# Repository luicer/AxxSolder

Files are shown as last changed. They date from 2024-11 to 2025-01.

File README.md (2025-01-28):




<a href='https://ko-fi.com/axxaxx' target='_blank'>Donate  

Interested in purchasing an AxxSolder 3.1? On [Tindie](https://www.tindie.com/stores/axxaxx/) you can purchase assembled and tested AxxSolder 3.1 boards with connectors and hardware.  


# AxxSolder Overview
AxxSolder is a STM32 based soldering iron controller for JBC C115, C210 and C245 style cartridges.  
Two different versions are designed around the same PCB and software - one soldering station based on the [JBC ADS stand](https://www.jbctools.com/ad-sf-stand-for-t210-t245-handles-product-2018.html) and one portable version. The AxxSodler hardware takes a DC input source of 9-24V OR a USB-C Power Delivery source. The recommended power supply is a Meanwell [LRS-150-24](#recommended-power-supply) which can power all compatible JBC irons at full power. If a 65W, 20V USB-PD supply is used then NT115 and T210 handles can be powered at full power and T245 at limited power. The power limiting is automatic and AxxSolder reads the power capability of the USB-PD source during the negotiating phase and reduces the output power accordingly.  
The software is written for the [STM32G431CBT6](https://www.st.com/en/microcontrollers-microprocessors/stm32g431cb.html) and implements a PID controller for temperature regulation, TFT display driver, sleep functions for when the handle is at rest and various user settings to name a few.  
Enclosures for both station and portable versions are 3D printed and design files are available under [/CAD](https://github.com/AxxAxx/AxxSolder/tree/main/CAD). A video showing the AxxSolder station can be found under [DEMO](#demo). A *bill of materials* (BOM) with individual component prices can be found under [/bom](https://github.com/AxxAxx/AxxSolder/tree/main/AxxSolder_hardware/bom).  
coverphoto

# Questions and support
Please use [Discord](https://discord.gg/AwpHEmsyKj) for build related and general questions.

# Table of Contents
- [AxxSolder Overview](#axxsolder-overview)
- [Questions and support](#questions-and-support)
- [Features](#features)
- [DEMO](#demo)
- [Schematic](#schematic)
- [PCB](#pcb)
- [Software Version History and Hardware Compatibility](#software-version-history-and-hardware-compatibility)
- [AxxSolder Station](#axxsolder-station)
- [AxxSolder Portable](#axxsolder-portable)
- [Recommended power supply for tip grounding](#recommended-power-supply-for-tip-grounding)
- [Handle identification and connections](#handle-identification-and-connections)
- [Firmware update](#firmware-update)
- [First start up after build](#first-start-up-after-build)
- [Settings](#settings)
- [PID control](#pid-control)
- [Cartridge differences](#cartridge-differences)
- [Temperature calibration](#temperature-calibration)
- [Temperature measurement](#temperature-measurement)
- [Current measurement](#current-measurement)
- [Disclaimer](#disclaimer)

# Features
- The tip temperature is set by a rotary encoder. Pressing the encoder puts AxxSolder into Sleep mode and heating is turned off, press again to wake up.  
- AxxSolder is capable of driving C115, C210 and C245 style cartridges from JBC. With two handle sense inputs AxxSolder can determine if the connected handle is either a NT115, T210 or T245 and adjust max output power accordingly. The max output power is software limited to 130 W for T245, 65 W for T210 and 22 W for NT115 handles.
- When the handle is put into the stand (connected to Stand_sense) AxxSolder goes into "Standby mode". On the portable version an aluminium plate is mounted in the case and allows the AxxSolder to go into Standby mode when the cartridge or handle rests against it. After 10 min in Standby mode AxxSolder goes into "Sleep mode" and heating is completely turned off. This is similar to what JBC calls [Sleep and Hibernation](https://www.jbctools.com/intelligent-heat-management.html).  
- If AxxSolder is left in normal running mode for longer than 30 min, the station automatically goes into sleep mode after 30 min as a safety feature.  
- Should the temperature ever go higher than 480 deg C overheating is detected and the station goes into sleep mode in order to protect the tip.
- At start-up any USB-PD source is detected and the highest possible power is negotiated. AxxSolder limits the soldering iron output power to the max output power of the USB-PD source automatically. The maximum power output is displayed at the top of the power bar graph on the display.
- User settings are stored in non-volatile flash and can be configured via a settings menu described in [SETTINGS](#settings).
- The two buttons are used to store temperature presets, e.g. 330 deg C and 430 deg C. Both preset temperatures are configurable in the settings menu.
- There is a 3.3 V logic level output (GPIO4) that can be configured to go high when the iron is in Run mode, controlling e.g. fume extractor via a MosFET or relay.
- The TFT display used in this project is a 2 inch 320x240 Color TFT display [2.0" 320x240 Color IPS TFT Display](https://www.adafruit.com/product/4311) and shows information about:
  - Set temperature
  - Actual temperature
  - Current power as a bar graph
  - In case of sleep mode, the power bar shows "ZzZzZz"
  - In case of Standby mode, the power bar shows "STANDBY"
  - Input voltage
  - MCU temperature
  - Current detected handle type
  - Current max power output
  - Current power source USB-PD / DC

# DEMO
YouTube (https://www.youtube.com/watch?v=I5uLvEM9wpY)
[https://www.youtube.com/watch?v=I5uLvEM9wpY](https://www.youtube.com/watch?v=I5uLvEM9wpY)

# Schematic
The schematic for AxxSolder is shown below. Both station and portable versions use the same PCB and software. The MCU is a [STM32G431CBT6](https://www.st.com/en/microcontrollers-microprocessors/stm32g431cb.html). 
AxxSolder_station

# PCB
The PCBs are designed in KiCad and manufactured by [PCBWay](https://www.pcbway.com/). PCBWay has sponsored this project with PCBs and stencils. The support and quality from PCBWay is great and therefore PCBWay is the recommender PCB supplier for this project. As some components have a rather fine pitch (0,5 mm as of the LQFP-48 package of the STM32) and some packages are "no lead" with a bottom thermal pad e.g. the WSON-8 package of the OPA2387 it is recommended to use a stencil to apply solder paste and then reflow the board using either a reflow oven or hot-plate. The boards on the image below were reflowed on a hot-plate (a homemade AxxPlate). A microscope is also recommended and helpful during assembly.
Printed Circuit Boards with assembled components are shown in the image below.
PCB_image
A 3D view (from and back) of the AxxSolder PCB is generated with KiCad and shown below. 
PCB_3D

# Software Version History and Hardware Compatibility
| Version | Date  | Hardware Compatibility |
|---|---|---|
|[v3.3.1](https://github.com/AxxAxx/AxxSolder/releases/tag/v3.3.1)|Jan 18, 2025|V3.*|
|[v3.3.0](https://github.com/AxxAxx/AxxSolder/releases/tag/v3.3.0)|Jan 04, 2025|V3.*|
|[v3.2.5](https://github.com/AxxAxx/AxxSolder/releases/tag/v3.2.5)|Jan 02, 2025|V3.*|
|[v3.2.4](https://github.com/AxxAxx/AxxSolder/releases/tag/v3.2.4)|Dec 26, 2024|V3.*|
|[v3.2.3](https://github.com/AxxAxx/AxxSolder/releases/tag/v3.2.3)|Dec 05, 2024|V3.*|
|[v3.2.2](https://github.com/AxxAxx/AxxSolder/releases/tag/v3.2.2)|Nov 15, 2024|V3.*|
|[v3.2.1](https://github.com/AxxAxx/AxxSolder/releases/tag/v3.2.1)|Sep 21, 2024|V3.*|
|[v3.2.0](https://github.com/AxxAxx/AxxSolder/releases/tag/v3.2.0)|Aug 13, 2024|V3.*|
|[v3.1.0](https://github.com/AxxAxx/AxxSolder/releases/tag/v3.1.0)|Jun 5, 2024|V3.*|
|[v3.0.2](https://github.com/AxxAxx/AxxSolder/releases/tag/v3.0.1)|Apr 25, 2024|V3.*|
|[v3.0.1](https://github.com/AxxAxx/AxxSolder/releases/tag/v3.0.1)|Mar 26, 2024|V3.*|
|[v3.0.0](https://github.com/AxxAxx/AxxSolder/releases/tag/v3.0.0)|Mar 02, 2024|V3.*|
|[v2.2.4](https://github.com/AxxAxx/AxxSolder/releases/tag/v2.2.2)|Dec 11, 2023|V2.*|
|[v2.2.4](https://github.com/AxxAxx/AxxSolder/releases/tag/v2.2.2)|Nov 28, 2023|V2.*|
|[v2.2.3](https://github.com/AxxAxx/AxxSolder/releases/tag/v2.2.2)|Nov 25, 2023|V2.*|
|[v2.2.2](https://github.com/AxxAxx/AxxSolder/releases/tag/v2.2.2)|Oct 24, 2023|V2.*|
|[v2.2.0](https://github.com/AxxAxx/AxxSolder/releases/tag/v2.2.0)|Oct 20, 2023|V2.*|
|[v2.1.3-revC](https://github.com/AxxAxx/AxxSolder/releases/tag/v2.1.3-revC)|Oct 16, 2023|V2.*|
|[v2.1.1](https://github.com/AxxAxx/AxxSolder/releases/tag/v2.1.1)|Oct 7, 2023|V2.*|
|[v2.1.0](https://github.com/AxxAxx/AxxSolder/releases/tag/v2.1.0)|Oct 7, 2023|V2.*|

# AxxSolder Station
The preferred setup is to pair AxxSolder with the [JBC ADS stand](https://www.jbctools.com/ad-sf-stand-for-t210-t245-handles-product-2018.html). This makes a very nice, compact and powerful soldering station. The JBC ADS stand is paired with a custom 3D printed enclosure for AxxSolder and the PCB is mounted with two mounting brackets. All 3D printed parts are available under [/CAD](https://github.com/AxxAxx/AxxSolder/tree/main/CAD). 
AxxSolder_station  
The JBC ADS stand comes with a silicone cable fitted with two Binder 99-0621-00-07 connectors. In order to use this cable a Binder 99-0624-00-07 is mounted into the AxxSolder enclosure and wired as the image below:  
AxxSolder_station  
By default, the stand separates the two signals coming from the "tool rest position" and the "tip change position" and does NOT have two separate connections for tip sensing 1 and 2 as is needed if NT115, T210 and T245 handles should all be automatically detected. Therefore, a modification is done to the PCB inside the JBC ADS stand in order to combine the "tool rest position" and the "tip change position" sense into one connection and separate the two tip sense connections. This is shown in the image above. The stand is held together with two PH0 screws from the side.  
NOTE: This modification of the stand is NOT necessary if you know that you will not be using NT115 handles and only require automatic detection of T210 and T245 handles.  
The JBC ADS stand is a expensice piece and thankfully there are many alternatives online for the one who wants to save some money. The community on the AxxSolder Discord channel has created many enclosures for alternative stands.

# AxxSolder Portable
It is often nice to have a compact and portable soldering iron controller for when you are away from your comfortable desk. A neat powerful package with the same capabilities as your main soldering station. This is why AxxSolder Portable was designed. The only difference between AxxSolder station and Portable is the enclosure.  
As AxxSolder accepts an input of 9-24 V it is compatible with a range of battery options. The author usually use a battery pack consisting of 12 Samsung INR18650 35E in a 3S4P configuration which works very well.  
The portable version has an aluminium tab on the enclosure connected to the same input on the PCB as the "handle rest" on the station version. This allows the user to rest the iron onto the aluminium tab and automatically enter sleep mode.   
AxxSolder_portable
The connections from the handle to the PCB through the Hirose RPC1-12RB-6P(71) connector is shown below. The Stand_sense in the portable version is connected to the aluminium plate which tells the AxxSolder to go into sleep mode when in contact with the soldering iron.  
AxxSolder_portable

# Recommended power supply for tip grounding
In order to be able to ground the tip of the soldering iron the user MUST use a power supply with a floating output (SELV) and connect protective earth to the ground terminal on AxxSolder. No other devices should share this DC power other than AxxSolder itself. A well-suited power supply with floating output (SELV) is the Meanwell LRS-150-24. It is rated for 156 W at 24 V. By using this kind of power supply, AxxSolder can be connected directly its DC output and to mains earth thus keeping the tip of the soldering iron at earth ground potential. There is a 1A fuse after the earth terminal in paralell with a 1M resistor on the AxxSolder.  
A printable cover protecting the terminals of the for LRS-150-24 can be found under [/CAD](https://github.com/AxxAxx/AxxSolder/tree/main/CAD).  
LRS-150-24
Another suitable power supply is the Meanwell XLG-150-24 which has a slightly different form factor and is fully enclosed.

# Handle identification and connections
In order for AxxSolder to know which type of handle (NT115, T210, T245) is attached specific pins inside the handle connector must be connected (bridged with a jumper wire). By default, the original JBC handle T245 has NO bridged pins while inside the connector of the original JBC T210 the pins 5 and 6 are bridged with a jumper wire. The original NT115 handle from JBC has a different connector and must be modified accordingly. All the necessary connections are shown in the image below.  
When powering on AxxSolder for the first time after doing these connections inside the handle connector it is wise to attach a handle without its cartridge and ensure that AxxSolder detects and shows the correct handle type on the display.  
Failing to detect the handle type may cause permanent damage to the cartridge as the temperature calibration and max allowed power will be wrong.  
❗WARNING❗ It has been discovered that some JBC clones have different pins bridged by the manufacturer. For example: Some AiXun T210 handles have pin 1 and 6 bridged, instead of pin 5 and 6 as AxxSolder requires for T210 handles. It is however easy to open up the connector and do the required pin connection.      
Handle_connections

# Firmware update
Flashing or updating the firmware on the STM32 MCU can be done in two ways, by using a SWD programmer or directly via USB. 
There is a bug in the new ST Programmer software version 2.17 throwing the error: "Error: Database: There's no active configuration for this device.  All the 3 configurations are disabled!" when trying to connect to the MCU.  
Download version 2.15 instead:
STprogrammer_2_15

## SWD programmer
These come in a variety of models and are available from several different places online. In the below example a [STLINK-V3MINIE](https://www.st.com/en/development-tools/stlink-v3minie.html) SWD programmer is used. The MCU is programmed by the following steps:
1. Disconnect any soldering iron handles from AxxSolder during the firmware update process.
2. Download the latest AxxSolder.bin file from [Releases](https://github.com/AxxAxx/AxxSolder/releases)
3. Connect your SWD programmer to the target MCU with GND, 3.3V, (N)RST, SWCLK, SWDIO
4. If your SWD programmer *can not* supply 3.3V it is necessary to power the AxxSolder from an external supply.
5. Start your programming software. [STM32CubeProgrammer](https://www.st.com/en/development-tools/stm32cubeprog.html) is used in this example.
6. Connect to the target by selecting *ST-LINK* and click on *Connect*
7. Load the latest AxxSolder.bin downloaded in *Step 2* by clicking *Open file* and select the downloaded binary file.
8. Write the firmware to the MCU by clicking *Download*.
9. If you get the message *File download complete* everything succeeded and the SWD programmer can be disconnected and AxxSolder power cycled once and AxxSolder should boot.


AxxSolder_SWD_programming
## USB (DFU mode)
1. Disconnect any soldering iron handles from AxxSolder during the firmware update process.
2. Download the latest AxxSolder.bin file from [Releases](https://github.com/AxxAxx/AxxSolder/releases)
3. Connect AxxSolder via USB to a computer that runs [STM32CubeProgrammer](https://www.st.com/en/development-tools/stm32cubeprog.html).
4. Hold down the most right button while powering on AxxSolder to enter DFU mode.
5. Connect to the target by selecting *USB* and click on *Connect*
6. Load the latest AxxSolder.bin downloaded in *Step 2* by clicking *Open file* and select the downloaded binary file.
7. Write the firmware to the MCU by clicking *Download*.
8. If you get the message *File download complete* everything succeeded and the USB cable can be disconnected.
9. Power cycle once and AxxSolder should boot.

# First start up after build
The first start up after you have built your AxxSolder can be intense. Double check all solder connections under a loupe/microscope. Especially the OPA2387, LTC4440 and the STM32G431 are small packages with tight pad spacing and can have solder bridges. Do also double check the connections to the soldering iron/stand which are shown in this document under [AxxSolder Station](#axxsolder-station) and [AxxSolder Portable](#axxsolder-portable).  
The first thing to do after you have double-checked everything is to follow the steps under [Firmware update](#firmware-update). It is wise to do the first programming of AxxSolder without any handle piece and with only 3.3 V, not VDD. After the programming is done you can now power up AxxSolder again via either with 3.3 V, this time you can attach your handle. This allows you to test that your handle type is detected correctly (the detected handle type NT115/T210/T245 is shown in the display). The Standby feature can also be tested by touching the stand (STAND Input).  
If the handle is detected correctly, the Standby function works and the display works you proceed to test the 7.35V DC/DC. This is done by once again disconnect the handle, but this time apply current limited 9-24 V VDD. 100 mA at 24 V is enough to check that the display starts and that you can measure the 3 bus voltages; 3.3V, 7.35V and VDD. If the bus voltages look good and the display shows the main screen you are ready to apply full VDD power and attach the soldering handle.  
If you are not 110% sure about your soldering/connections it is wise to be on the safe side and keep your soldering tip in a water bath in over to prevent it from over-heating in an uncontrolled manner. During the development this method was used and saved a few of those expensive JBC cartridges..

# Settings
To access the user settings the user holds down the encoder button at start-up. A SETTINGS text is then presented and the button can be released. While in the settings there are several parameters available.
| Setting | Description  | Unit | Default |
|---|---|---|---|
|Startup Temp °C|Default temperature selected after boot|deg C|330|
|Temp Offset °C|Temperature offset applied to measured temperature|deg C|0|
|Standby Temp °C|Temperature to go to after handle is set in stand|deg C|150|
|Standby Time [min]|Time for which standby temperature is held before cooling down|minutes|10|
|Sleep Time [min]|Time that the iron can be ON before cooling down (safety feature)|minutes|30|
|Buzzer Enable|Enable or Disable the buzzer|ON/OFF|ON|
|Preset Temp 1 °C|Preset temperature for button 1|deg C|330|
|Preset Temp 2 °C|Preset temperature for button 2|deg C|430|
|GPIO4 ON at run|Enable 3.3V output on GPIO4 when the iron is in run mode|ON/OFF|OFF|
|Screen rotation|Rotate the screen|"0"=-180 deg, "1"=-90 deg, "2"=0 deg, "3"=90 deg|2|
|Limit Power [W]|Limit the output power|"0"=no user limit, "5"=5 W, "10"= 10 W, "15"= 15 W ...|0|
|I measurement|Measure the heater current|ON/OFF|ON
|Startup beep|Beep after startup|ON/OFF|ON
|Temp in celcius|Show temperatures in Celcius and not Fahrenheit|ON/OFF|ON
|Temp cal 100 °C|Actual temperature at 100 °C|deg C|100|
|Temp cal 200 °C|Actual temperature at 200 °C|deg C|200|
|Temp cal 300 °C|Actual temperature at 300 °C|deg C|300|
|Temp cal 350 °C|Actual temperature at 350 °C|deg C|350|
|Temp cal 400 °C|Actual temperature at 400 °C|deg C|400|
|Temp cal 450 °C|Actual temperature at 450 °C|deg C|450|
|Serial DEBUG|Print debug over serial|ON/OFF|OFF|
|Displayed temp filter|Moving average filter length|Lenght|5|
|Startup temp is previous temp|Startup temp is previous used temp|ON/OFF|OFF|
|3-button mode|Use 3-button mode|ON/OFF|OFF|
|-Load Default-|Load default parameters|N/A|N/A|
|-Save and Reboot-|Exit and Save|N/A|N/A|
|-Exit no Save-|Exit without Save|N/A|N/A|

# PID control
The thermal mass and heat convection differs between different tip designs. Therefore the PID parameters should in theory be adjusted to each different cartridge. As a matter of simplification, the PID parameters are only different between the different handle types, NT115, T210 and T245. This gives a good thermal performance in conducted tests.
```c
/* Cartridge type specific PID parameters */
#define KP_NT115        5
#define KI_NT115        2
#define KD_NT115        0.3
#define MAX_I_NT115     300

#define KP_T210         7
#define KI_T210         4
#define KD_T210         0.3
#define MAX_I_T210      300

#define KP_T245         8
#define KI_T245         2
#define KD_T245         0.5
#define MAX_I_T245      300

/* General PID parameters */
#define PID_MAX_OUTPUT          500
#define PID_UPDATE_INTERVAL     25
#define PID_ADD_I_MIN_ERROR     75
double PID_NEG_ERROR_I_MULT =   7;
double PID_NEG_ERROR_I_BIAS =   1;

/* Max allowed power per handle type */
#define NT115_MAX_POWER         22
#define T210_MAX_POWER 	        65
#define T245_MAX_POWER 	        130
```
The PID parameters are adjusted to achieve a fast response with minimum overshoot and oscillation. The below image is showing the set temperature, actual temperature response as well as the P, I and D contributions during a heat-up cycle from 25 deg C to 330 deg C. This heat-up sequence takes ~1.5 seconds for a C210-007 cartridge.  

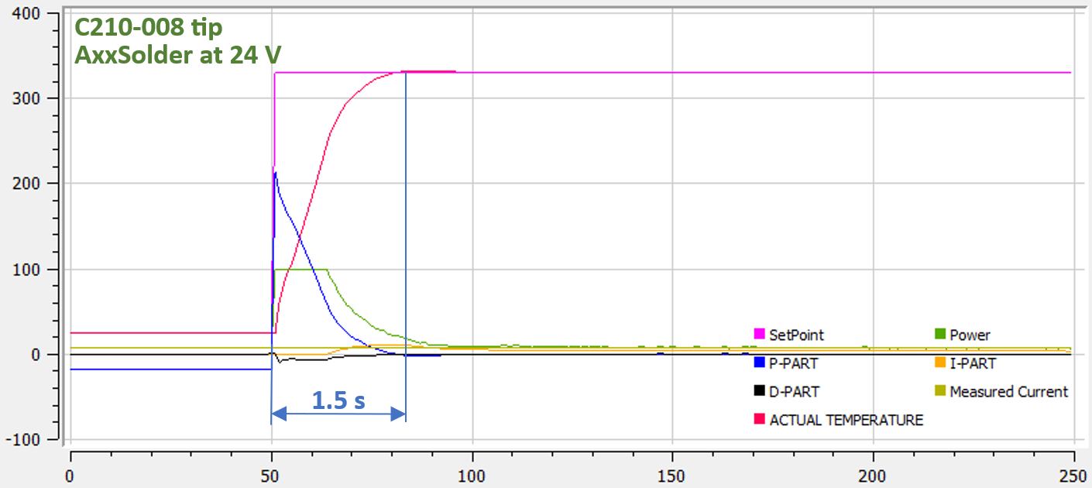
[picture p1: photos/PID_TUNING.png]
AxxSolder_pid
 

# Cartridge differences
Cartridges from JBC do all contain a thermocouple element to read the tip temperature and a resistive heater element. The configuration of thermocouple and heater element differ slightly between cartridge models. In order to determine the internal configuration of the cartridges two cross sections were done. These show clearly how the C210 and C245 cartridges are constructed internally. The images can be seen here: [https://www.eevblog.com/forum/projects/axxsolder-jbc-soldering-controller](https://www.eevblog.com/forum/projects/axxsolder-jbc-soldering-controller/msg5124267/#msg5124267).  
As the thermocouple output also differs (see my measurements [Temperature calibration](#temperature-calibration)) the correct handle/cartridge type has to be set. This is done automatically be the inputs "Handle_sense_1" and "Handle_sense_2" This can be done thanks to the design of the handle connector. For the JCB T210 handle pin 5 and 6 are connected internally in the connector and for NT115 pin 3 and 5 should be connected. This allows AxxSolder to sense which handle is connected and assign correct thermocouple correction, PID parameters and max output power.
 
# Temperature calibration
The voltage from the thermocouple embedded inside the cartridge is amplified by an OPA2387 operational amplifier and then read by the ADC of the MCU. To correlate the measured ADC value to the cartridge temperature experiments were done. A constant power was applied to the heating element of the cartridge and the ADC value was read as well as the actual tip temperature. The tip temperature was measured by a "Soldering Tip Thermocouple" used in e.g. the Hakko FG-100.   
The measured data was recorded and plotted for both the C115, C210 and C245 cartridges. The specific cartridges used were the C115112, C210-007 and C245-945. The measured data were fitted to polynomial equations:  
$Temp_{C115}[deg] =  5.10e^{-5} * ADC^2 + 0.42* ADC + 20.15$  
$Temp_{C210}[deg] =  4.22e^{-6} * ADC^2 + 0.32* ADC + 20.97$  
$Temp_{C245}[deg] = -4.73e^{-7} * ADC^2 + 0.12* ADC + 23.78$  
These are then used in the software to retrieve correct tip temperatures.
Temp_calibration

The user can adjust the temperature calibration at 6 points in order to compensate for variations in the cartridge thermocouple.  
To calibrate temperature(s):
- Make sure that the temperature calibration values are at their default nominal values in the settings.
- Set AxxSolder to the temperature that you want to calibrate. for example 300 deg C.
- When AxxSolder stabilizes around the setpoint, measure the actual tip temperature by using a soldering tip thermocouple, for example the HAKKO FG-100B.
- Input the actual measured temperature, let's say 302 deg C into the 300 deg C calibration setting ("Temp cal 300" = 302).
  
AxxSolder will then use this calibration point and correct the temperature accordingly. It will do so linearly between all calibration points.

# Temperature measurement
As the thermocouple and heater element is connected in series inside the JBC cartridges and the thermocouple voltage measures over the same pins as the heating element we have to be careful when to do the temperature measurement. In order to not disturb the thermocouple measurement with heater element switching, the switching is turned off for 0.5 ms just before the temperature measurement is taken. The 0.5 ms delay ensures that the switching is turned off and the thermocouple signal is stabilized around a stable voltage.  
The measured signal over the thermocouple is clamped to 3.3V with a BAV199 Schottky diode in order to protect the op-amp OPA2387. The voltage measurement is taken by the internal ADC in DMA mode with a circular buffer. The buffer holds several measurements which are averaged and filtered in software.  
The yellow curve in the image below (Channel 1) shows the PWM signal driving the gate of the MOSFET.  
The green curve shows the amplified voltage between GREEN and RED wire in the JBC handle for at 330 degree C and 5% power and the purple 25 degree C and at 80% power (the tip held under water trying to heat up).  
The blue pulse indicates the wait time of 0.5 ms and the purple pulse is where the ADC is sampled.
Oscilloscope_image_PWM
# Current measurement
The current is sampled four times per second by a 30 us current pulse through the heater. This is done both to check if there is a functioning tip in the handle (otherwise the display shows "---" at current temp) and to be able to calculate the power drawn by the heater. By knowing how much the heater draws in ampere the actual power can be calculated by knowing the bus voltage and pulse duty cycle. to measure the current the gate to the MOSFET is turned on, 10 us later the voltage over the current shunt is sampled by the ADC and the result is converted. This is shown the image below.
Oscilloscope_image_PWM
# Disclaimer
AxxSolder is an open source project and has absolutely no warranty, or guarantees on functionality or reliability! The authors of this project accept absolutely no liability for any harm or loss resulting from its use. That said, have fun. :)
## Stargazers over time
Stargazers over time (https://starchart.cc/AxxAxx/AxxSolder)

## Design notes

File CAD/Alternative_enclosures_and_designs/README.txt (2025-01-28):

In this folder you can find alternative CAD models of enclosures that others have designed.

The owner (AxxAxx) of the AxxSolder repo do not take credit nor provide support for these designs. 
But they are probably very nice and of good quality if they have been merged into here! :)

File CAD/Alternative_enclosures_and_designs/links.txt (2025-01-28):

https://www.printables.com/model/894013-mini-iron-man-soldering-station-for-jbc-handpieces
https://www.printables.com/model/875115-25u-19-inch-rack-front-panel-mount-for-axxsolder-3

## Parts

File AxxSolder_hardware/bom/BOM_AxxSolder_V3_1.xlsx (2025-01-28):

AxxSolder V3.1 | Prises as per 2024-02-20 | Parts for AxxSolder Portable
 |  | Parts for AxxSolder Station
References | Value | Footprint | Manufacturer | MPN | Mouser Part Number | Quantity | Price per part | Price total | Price total inc tax
C3, C9, C14, C15, C16, C17, C18, C21, C22, C23, C24, C25, C26, C27, C28, C29, C33 | 100n | C_0603_1608Metric | KEMET | C0603C104J5RACTU | 80-C0603C104J5R | 17 | 0.04 € | 0.73 € | 0.91 €
C1, C2, C5, C7, C8, C10, C11, C12, C13, C19, C20, C30, C31, C32, C34, C35 | 10u | C_0603_1608Metric | Murata Electronics | GRM188R6YA106MA73J | 81-GRM188R6YA106MA3J | 16 | 0.18 € | 2.83 € | 3.54 €
C4, C6 | 1n | C_0603_1608Metric | KEMET | C0603C102K3GAC | 80-C0603C102K3G | 2 | 0.09 € | 0.19 € | 0.23 €
C37 | 220u | CAPAE830X1050N | KEMET | EEV227M035A9MAA | 80-EEV227M035A9MAA | 1 | 0.61 € | 0.61 € | 0.77 €
R4, R6, R18, R19, R20, R22, R23, R25, R26, R27, R28, R29, R30, R31, R32, R33, R35, R36, R37, R38 | 4k7 | R_0603_1608Metric | Panasonic | ERJ-3RBD4701V | 667-ERJ-3RBD4701V | 20 | 0.12 € | 2.50 € | 3.12 €
R11, R12, R15, R21, R24 | 22k | R_0603_1608Metric | Panasonic | ERJ-UP3J223V | 667-ERJ-UP3J223V | 5 | 0.14 € | 0.70 € | 0.88 €
R1, R5, R14, R17 | 1k5 | R_0603_1608Metric | Panasonic | ERJ-H3ED1501V | 667-ERJ-H3ED1501V | 4 | 0.21 € | 0.86 € | 1.07 €
R2, R7, R8, R9 | 360k | R_0603_1608Metric | Panasonic | ERJ-3RED3603V | 667-ERJ-3RED3603V | 4 | 0.12 € | 0.48 € | 0.60 €
R3, R10 | 220k | R_0603_1608Metric | Panasonic | ERJ-3RED2203V | 667-ERJ-3RED2203V | 2 | 0.12 € | 0.24 € | 0.30 €
R13, R16, R34, R43, R46, R47, R48 | 100 | R_0603_1608Metric | Panasonic | ERJ-P03F1000V | 667-ERJ-P03F1000V | 7 | 0.31 € | 2.15 € | 2.69 €
R42 | 5m | RESC6432X89N | Vishay | WSLP25125L000FEA | 71-WSLP25125L000FEA | 1 | 0.75 € | 0.75 € | 0.94 €
R44 | 1M | R_0805_2012Metric | Panasonic | ERJ-6GEYJ105V | 667-ERJ-6GEYJ105V | 1 | 0.09 € | 0.09 € | 0.12 €
R45 | 100m | R_0805_2012Metric | Panasonic | ERJ-6DSFR10V | 667-ERJ-6DSFR10V | 1 | 0.41 € | 0.41 € | 0.51 €
L1 | SRP7028CC-150M | INDPM7366X300N | Bourns | SRP7028CC-150M | 652-SRP7028CC-150M | 1 | 0.75 € | 0.75 € | 0.94 €
D5, D6, D7, D8 | BAT54S | SOT95P230X110-3N | Diotec Semiconductor | BAT54S | 637-BAT54S | 4 | 0.11 € | 0.45 € | 0.56 €
D1, D2 | BAV199WQ-7 | SOT65P210X110-3N | Diodes Incorporated | BAV199WQ-7 | 621-BAV199WQ-7 | 2 | 0.20 € | 0.39 € | 0.49 €
D3, D4 | SMF4L24AT1G | SODFL3619X98N | LITTELFUSE | SMF4L24AT1G | 576-SMF4L24AT1G | 2 | 0.40 € | 0.80 € | 1.00 €
D9, D10 | PMEG6020ER | PMEG6020ER115 | Nexperia | PMEG6020ER,115 | 771-PMEG6020ER-115 | 2 | 0.37 € | 0.74 € | 0.93 €
TFT1 | Adafruit_240x320_TFT | Adafruit_240x320_TFT | Adafruit | 4311 | 485-4311 | 1 | 18.55 € | 18.55 € | 23.19 €
U2 | RIC11-31S15D7-GSMT | RIC11-31S15D7-GSMT | CUI Devices (https://eu.mouser.com/manufacturer/cui-devices/) | RIC11-31S15D7-GSMT | 179-RIC1131S15D7GSMT | 1 | 2.37 € | 2.37 € | 2.96 €
U3 | BSC014N04LS | BSC014N04LS | Infineon Technologies | BSC014N04LSATMA1 | 726-BSC014N04LSATMA1 | 1 | 1.60 € | 1.60 € | 2.00 €
F1 | 0154007.DR | 0154100DR | LITTELFUSE | 0154007.DR | 576-0154007.DR | 1 | 2.55 € | 2.55 € | 3.19 €
F2 | SF-2410FP100W-2 | SF2410FP100W2 | Bourns | SF-2410FP100W-2 | 652-SF-2410FP100W-2 | 1 | 0.72 € | 0.72 € | 0.91 €
S2, S3 | ADTSM644RVTR | ADTSM644RVTR | Apem | ADTSM644RVTR | 642-ADTSM644RVTR | 2 | 0.55 € | 1.10 € | 1.37 €
FB1 | BLM18HE601SN1D | R_0603_1608Metric | Murata Electronics | BLM18HE601SN1D | 81-BLM18HE601SN1D | 1 | 0.18 € | 0.18 € | 0.22 €
IC1 | TLV76733DRVR | SON65P200X200X80-7N | Texas Instruments | TLV76733DRVR | 595-TLV76733DRVR | 1 | 0.38 € | 0.38 € | 0.48 €
IC2 | OPA2387DSGT | SON50P200X200X80-9N | Texas Instruments | OPA2387DSGT | 595-OPA2387DSGT | 1 | 4.40 € | 4.40 € | 5.50 €
IC3 | LMR54406DBVR | SOT95P280X145-6N | Texas Instruments | LMR54406DBVR | 595-LMR54406DBVR | 1 | 0.97 € | 0.97 € | 1.21 €
IC4 | STM32G431CBT6 | QFP50P900X900X160-48N | STMicroelectronics | STM32G431CBT6 | 511-STM32G431CBT6 | 1 | 5.65 € | 5.65 € | 7.06 €
IC5 | TPD4E1U06DBVR | SOT95P280X145-6N | Texas Instruments | TPD4E1U06DBVR | 595-TPD4E1U06DBVR | 1 | 0.33 € | 0.33 € | 0.41 €
IC6 | STUSB4500QTR | QFN50P400X400X100-25N-D | STMicroelectronics | STUSB4500QTR | 511-STUSB4500QTR | 1 | 2.52 € | 2.52 € | 3.15 €
IC7 | MAX16171ATA_VY+T | SON50P300X200X80-9N | Analog Devices | MAX16171ATA/VY+T | 700-MAX16171ATA/VY+T | 1 | 2.64 € | 2.64 € | 3.30 €
IC8 | LTC4440AHMS8E | SOP65P490X110-9N | Analog Devices | LTC4440AHMS8E-5#PBF | 584-C4440AHMS8E-5PBF | 1 | 5.22 € | 5.22 € | 6.52 €
IC9 | INA281A5QDBVRQ1 | SOT95P280X145-5N | Texas Instruments | INA281A5QDBVRQ1 | 595-INA281A5QDBVRQ1 | 1 | 2.74 € | 2.74 € | 3.43 €
LS1 | CMI-9653S-SMT-TR | CMI9653SSMTTR | CUI Devices | CMI-9653S-SMT-TR | 490-CMI-9653S-SMT-TR | 1 | 2.71 € | 2.71 € | 3.39 €
Q1 | STL9P3LLH6 | STL9P3LLH6 | STMicroelectronics | STL9P3LLH6 | 511-STL9P3LLH6 | 1 | 0.99 € | 0.99 € | 1.24 €
Q2 | STL10N3LLH5 | STL10N3LLH5 | STMicroelectronics | STL10N3LLH5 | 511-STL10N3LLH5 | 1 | 0.97 € | 0.97 € | 1.21 €
Q3 | 2N7002NXAKR | SOT95P230X110-3N | Nexperia | 2N7002NXAKR | 771-2N7002NXAKR | 1 | 0.13 € | 0.13 € | 0.16 €
J5, J6 | TSW-102-07-T-S | TSW-102-XX-YY-S | SAMTEC | TSW-102-07-T-S | 200-TSW10207TS | 2 | 0.09 € | 0.19 € | 0.23 €
J1 | USB4110-GF-A | USB4110GFA | GCT | USB4110-GF-A | 640-USB4110-GF-A | 1 | 1.26 € | 1.26 € | 1.57 €
J2 | 691243110009 | 691243110009 | Wurth Elektronik | 691243110009 | 710-691243110009 | 1 | 3.70 € | 3.70 € | 4.62 €
J4 | 61300611821 | RHDR6W97P0X254_1X6_1574X250X865P | Wurth Elektronik | 61300611821 | 710-61300611821 | 1 | 0.34 € | 0.34 € | 0.42 €
J7 | TSW-108-07-T-S | TSW-108-XX-YY-S | SAMTEC | TSW-108-07-T-S | 200-TSW10807TS | 1 | 0.59 € | 0.59 € | 0.74 €
SUM Components |  |  |  |  |  |  |  |  | €98.10
Hardware |  |  |  |  |  |  | Price inc tax
PCB (Development was done with PCBs from PCBWay, 2 layer, Immersion gold(ENIG) (1U")) + stencil |  |  |  | 1 | €12.62 | €12.62 | €15.77
Connector for JBC stand (binder 99-0624-00-07) |  |  |  | 1 | €5.11 | €5.11 | €6.39
Connector for soldering iron (HIROSE(HRS) RPC1-12RB-6P(71)) |  |  |  | 1 | €6.11 | €6.11 | €7.64
Power connector (Anderson PP15) BLACK | https://eu.mouser.com/ProductDetail/Anderson-Power-Products/1395G1?qs=yoCgdRjoRtHp7gSzhBTdjg%3D%3D |  |  | 2 | €0.95 | €1.90 | €2.37
Power connector (Anderson PP15) RED | https://eu.mouser.com/ProductDetail/Anderson-Power-Products/1395?qs=yoCgdRjoRtFIuHO4SWqMZA%3D%3D |  |  | 2 | €1.37 | €2.74 | €3.43
Power connector (Anderson PP15) GREEN | https://eu.mouser.com/ProductDetail/Anderson-Power-Products/1395G3?qs=yoCgdRjoRtE1BBke6hIRPA%3D%3D |  |  | 2 | €0.84 | €1.68 | €2.10
Rotary encoder knob | https://eu.mouser.com/ProductDetail/Davies-Molding/1101?qs=byeeYqUIh0PVJzrDf6EcyQ%3D%3D |  |  | 1 | €0.88 | €0.88 | €1.09
Tactile button caps | https://eu.mouser.com/ProductDetail/Omron-Electronics/B32-2000?qs=ZP3UR5XsUocRMlsFF2GtPw%3D%3D |  |  | 2 | €0.86 | €1.71 | €2.14
Rocker Switch | https://eu.mouser.com/ProductDetail/Wurth-Elektronik/471001264143?qs=YCa%2FAAYMW03bZZ%252BoQThfXw%3D%3D |  |  | 1 | €3.45 | €3.45 | €4.31
3D printed housing |  |  |  | 1 | €5.00 | €5.00 | €6.25
Screws - M2.5x12mm countersunk | To mount the PCB to enclosure |  |  | 4 | €0.10 | €0.40 | €0.50
Screws - M2.5x20mm | To mount PP15 connectors |  |  | 1 | €0.10 | €0.10 | €0.12
Screws - M4x8mm | For enclosure to JBS stand |  |  | 1 | €0.20 | €0.40 | €0.50
Screws - M2.5x6mm | To mount HIROSE(HRS) RPC1-12RB-6P(71) |  |  | 4 | €0.10 | €0.40 | €0.50
Screws - M2x8mm + nuts | For the aluminium rest |  |  | 2 | €0.10 | €0.20 | €0.25
Aluminium plate 15x10x2 mm | For the aluminium rest (not mandatory) |  |  | 1 | €1.00 | €1.00 | €1.25
SUM Hardware (portable) |  |  |  |  |  |  | €43.42
JBC stand
JBS Stand | https://www.jbctools.com/ad-sf-stand-for-t210-t245-handles-product-2018.html | https://eleshop.eu/jbc-ad-sf-stand-for-t245-and-t210.html |  | 1 | €171.40 | €171.40 | 214.25
Non-genuine Stand
Non-brand Stand | https://www.aliexpress.com/i/1005005756505193.html |  |  | 1 | €17.00 | €17.00 | €21.25
JBC T210 handle piece
T210 handle piece | https://www.jbctools.com/t210-a-precision-handle-product-48.html |  |  | 1 | €66.34 | €66.34 | €82.93
c210-008 tip | https://www.jbctools.com/c210008-chisel-cartridge-13-x-06-product-183.html |  |  | 1 | €38.34 | €38.34 | €47.93
Non-genuine JBC T210 handle piece
Aixun T210 handle piece | https://www.aliexpress.com/item/1005005081918036.html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 |  |  | 1 | €18.00 | €18.00 | €22.50
Aixun c210-008 tip | https://www.aliexpress.com/item/1005005879501637.html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 |  |  | 1 | €17.00 | €17.00 | €21.25

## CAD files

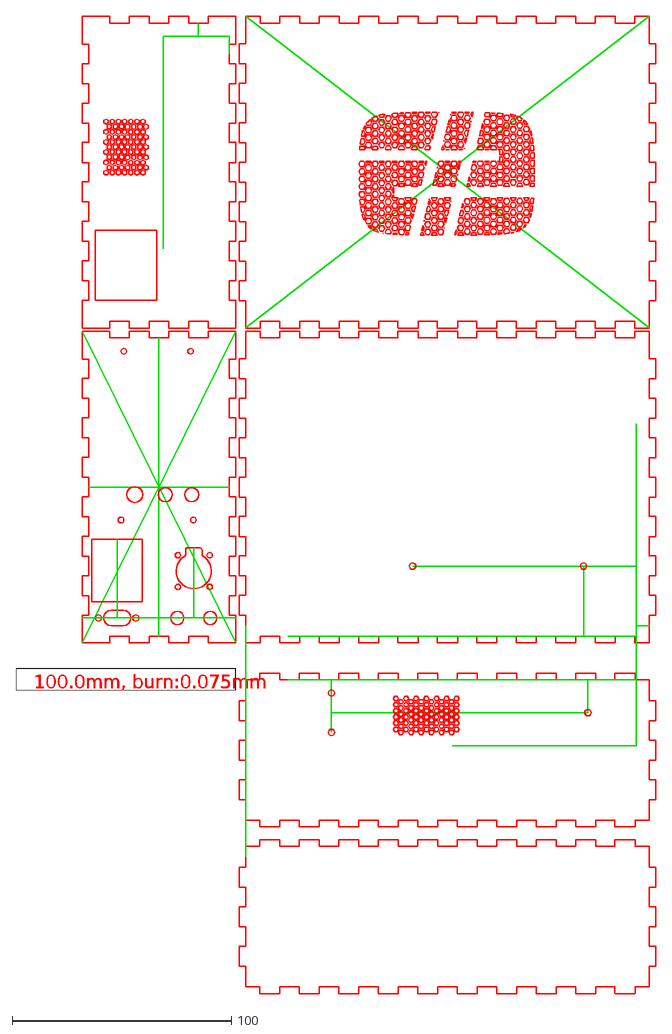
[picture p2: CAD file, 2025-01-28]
CAD/Alternative_enclosures_and_designs/AxxSolder-LaborStation/axxsolder-laborstation.dxf
100.0mm, burn:0.075mm

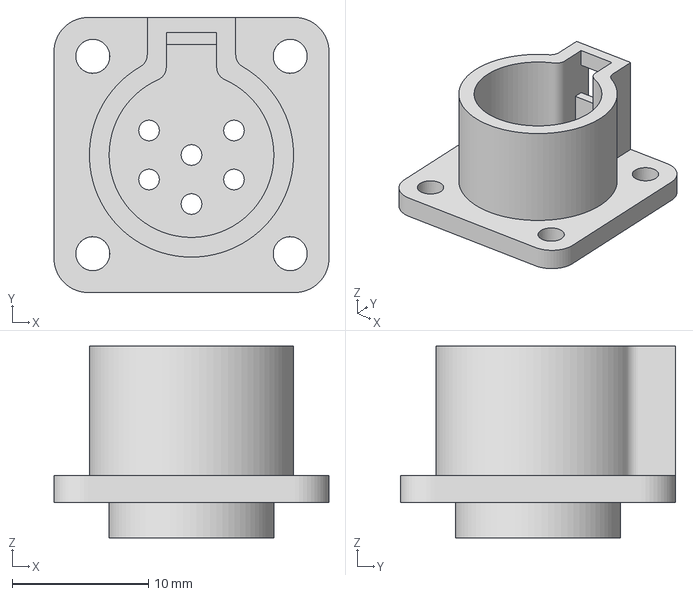
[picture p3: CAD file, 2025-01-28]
CAD/Alternative_enclosures_and_designs/RPC1-12RB-6P_3D_print/RPC1-12RB-6P.3mf
20.2 x 20.2 x 14.1 mm

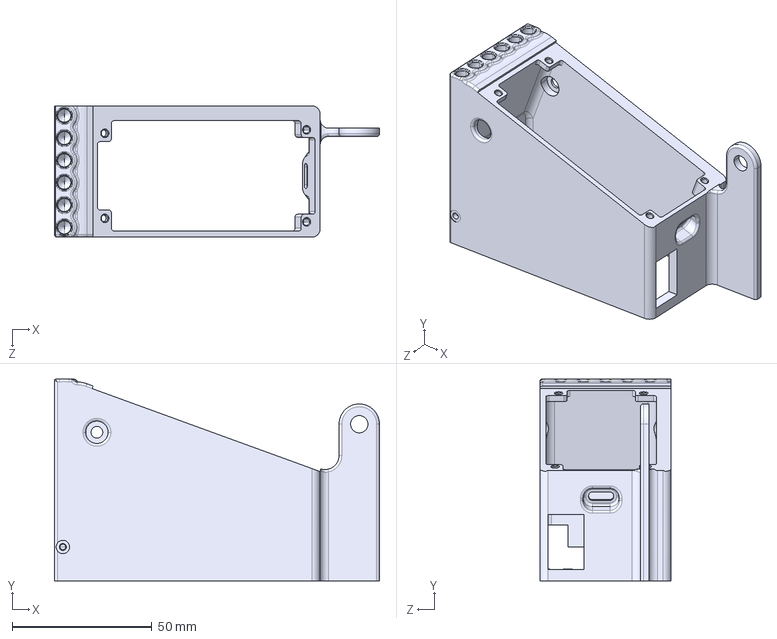
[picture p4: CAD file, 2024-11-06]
CAD/AxxSolder_JBC-ADS_stand/Encolsure_JBC-AD-SF_SEPARATED_TOP_bottom.STEP
116.5 x 72.2 x 47.1 mm

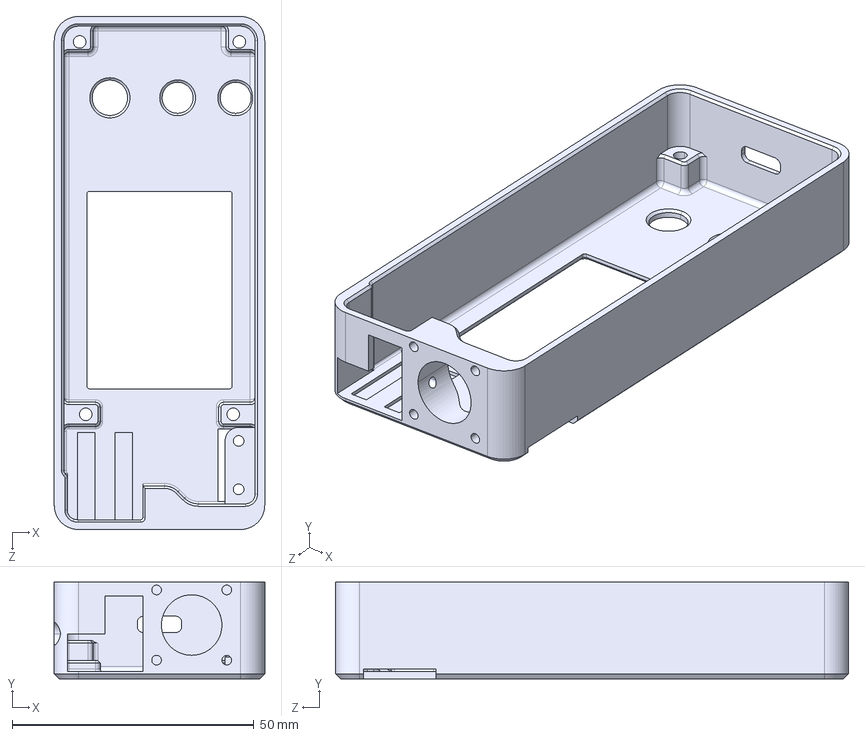
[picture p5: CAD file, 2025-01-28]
CAD/AxxSolder_Portable/AxxSolder_Encolsure_Portable_Top_Earth_Stand.STEP
43.5 x 20.0 x 106.0 mm

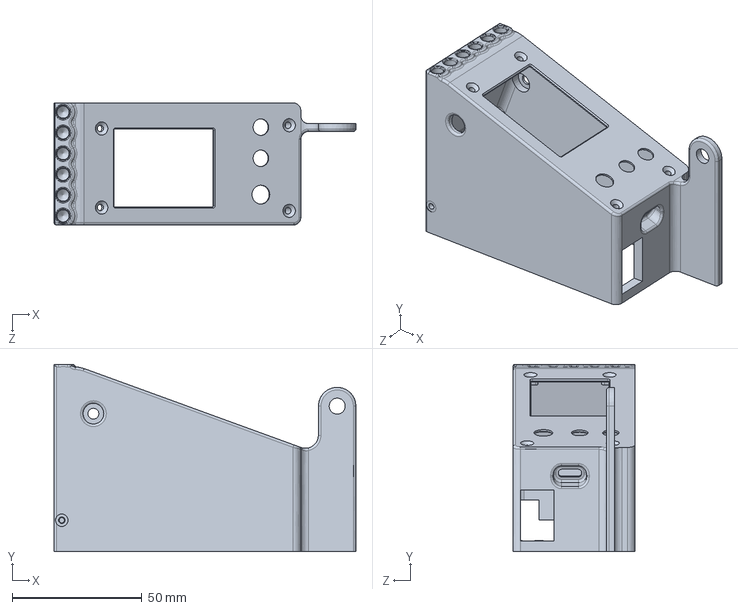
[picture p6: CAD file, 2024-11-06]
CAD/AxxSolder_JBC-ADS_stand/Encolsure_JBC-ADS.SLDPRT
116.5 x 72.2 x 47.1 mm

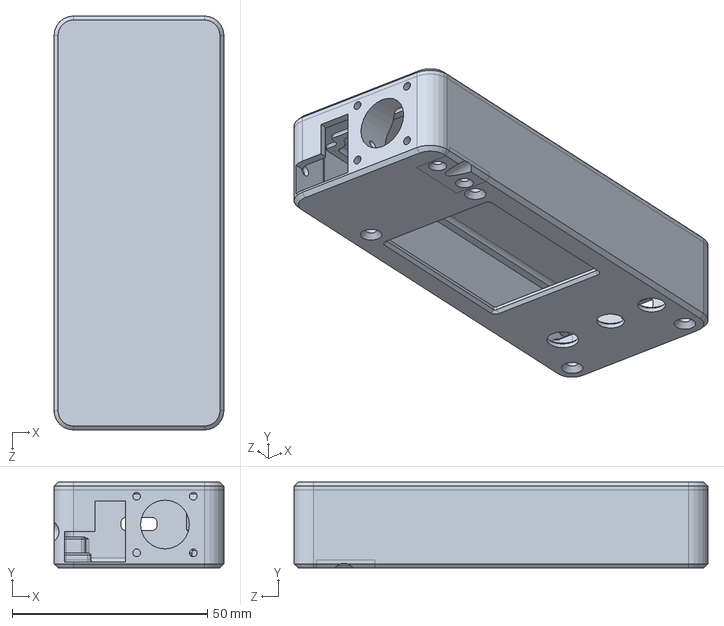
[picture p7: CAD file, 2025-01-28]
CAD/AxxSolder_Portable/Encolsure_Portable.SLDPRT
43.5 x 21.9 x 106.0 mm

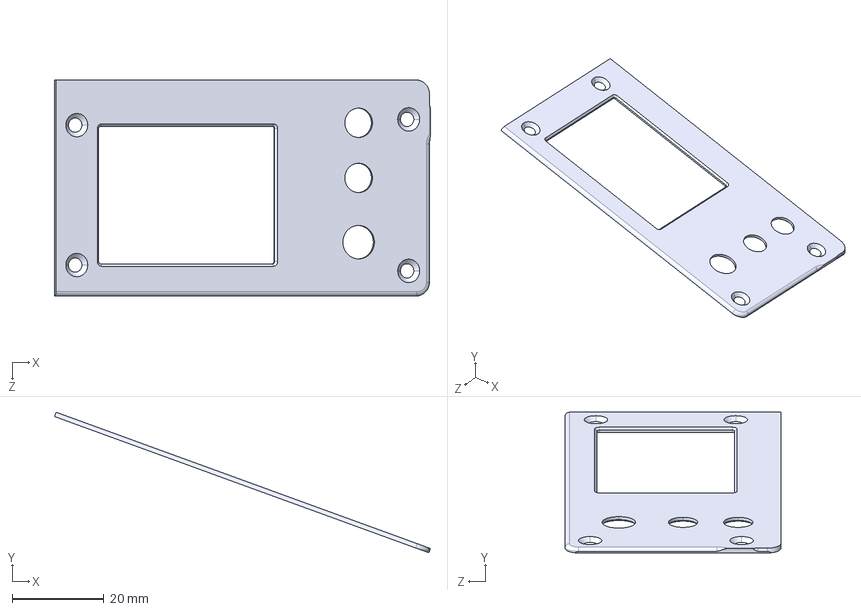
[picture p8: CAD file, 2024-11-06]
CAD/AxxSolder_JBC-ADS_stand/Encolsure_JBC-AD-SF_SEPARATED_TOP_top.STEP
81.9 x 30.6 x 47.1 mm

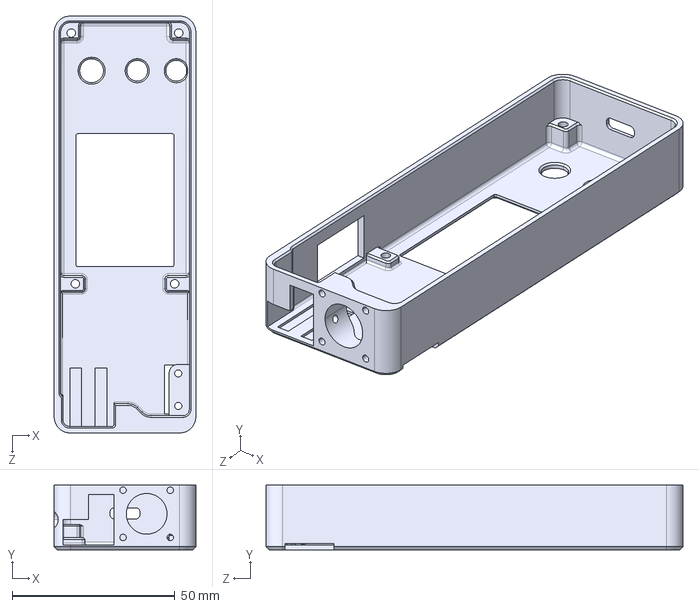
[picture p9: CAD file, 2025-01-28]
CAD/AxxSolder_Portable/AxxSolder_Encolsure_Portable_Top_Earth_Stand_RockerSwitch.STEP
43.5 x 20.0 x 128.0 mm

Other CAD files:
CAD/Alternative_enclosures_and_designs/RPC1-12RB-6P_3D_print/RPC1-12RB-6P.stl
CAD/Alternative_enclosures_and_designs/RPC1-12RB-6P_3D_print/RPC1-12RB-6P_v13.f3d
CAD/AxxSolder_JBC-ADS_stand/Encolsure_JBC-AD-SF_SEPARATED_TOP_bottom.STL
CAD/AxxSolder_JBC-ADS_stand/Encolsure_JBC-AD-SF_SEPARATED_TOP_top.STL

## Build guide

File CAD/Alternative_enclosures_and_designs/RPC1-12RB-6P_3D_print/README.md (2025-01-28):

# 3D Printed Housing
The parts can be sources from JLC3DP.com With the following parameters:
- MJF (NYLON)
- with PA12-HP Nylon
 
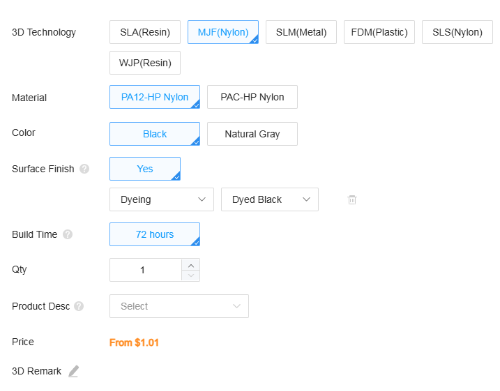
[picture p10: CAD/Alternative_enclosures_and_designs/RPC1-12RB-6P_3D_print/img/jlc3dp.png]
3d print at JLC3DP


# PCB
The gerber files and Easy EDA PCB is available in the PCB subfolder. There is no corresponding schematic, this was done by just placing vias on the PCB directly. The PCB is a 2 layer board, thickness 1.6mm.

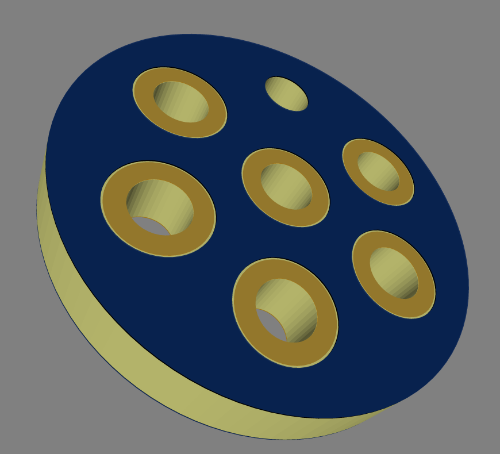
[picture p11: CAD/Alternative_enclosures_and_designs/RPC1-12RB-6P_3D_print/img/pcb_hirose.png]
pcb


## Pins
Mill-Max 1460-9-00-80-00-00-03-0 can be used to connect the PCB to the housing. The pins are available at 
[Mouser](https://www.mouser.de/ProductDetail/Mill-Max/1460-9-00-80-00-00-03-0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).

# Assembly
You have to make sure that the pins connect to the handle connector properly while not preventing the housing from being pushed all the way in.
A connector can be pushed into the 3D printed part for aligning the pins and the PCB. While still having everything put together the pins can soldered to the PCB. When having a HT Nylon part, the housing should be able to withstand soldering quickly.

Assembling the PCB apart from the housing is not recommended, since the tolerances of the housing and the handpiece connector are quite tight. It would be hard to get everything aligned properly. 

After assembly just use some wire cutters and trim the pins to the desired length.

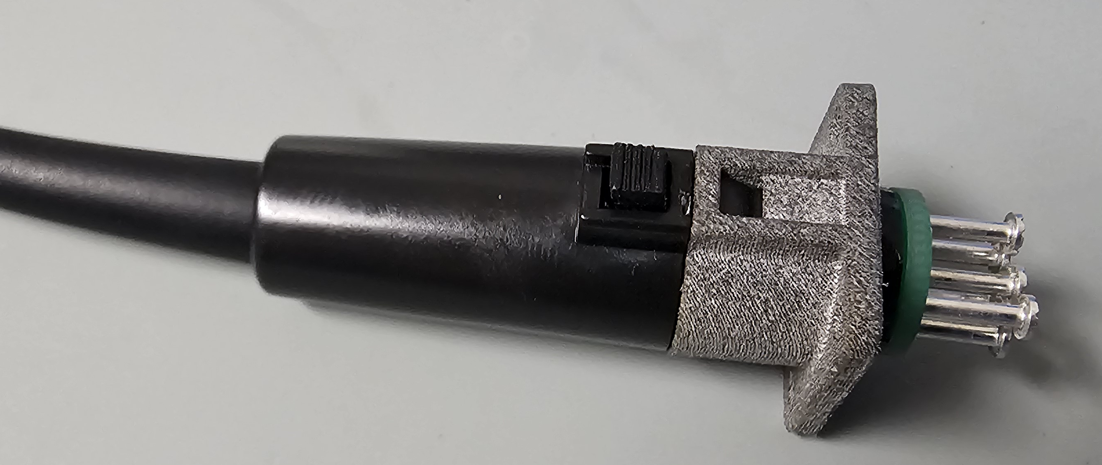
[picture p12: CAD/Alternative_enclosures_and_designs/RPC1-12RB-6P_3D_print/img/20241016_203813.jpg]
connector assembled

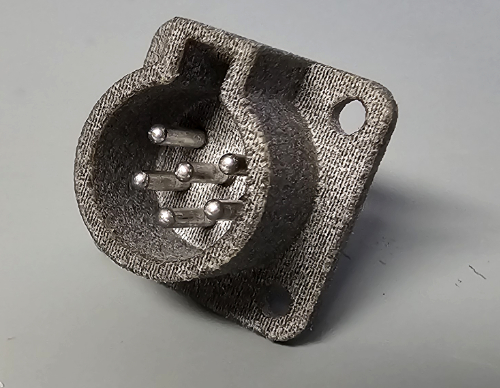
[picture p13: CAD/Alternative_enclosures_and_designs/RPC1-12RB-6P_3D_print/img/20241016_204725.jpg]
connector front

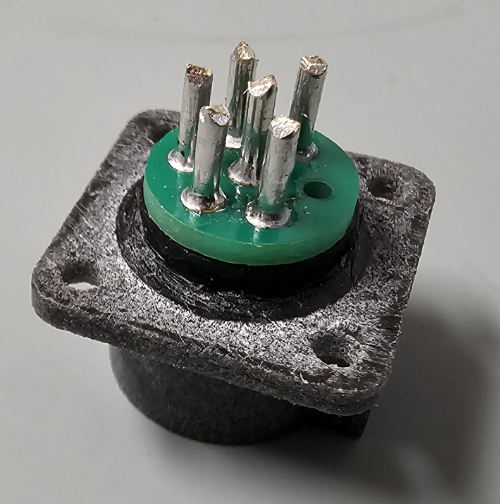
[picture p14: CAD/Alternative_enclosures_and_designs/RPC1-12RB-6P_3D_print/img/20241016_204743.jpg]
connector back


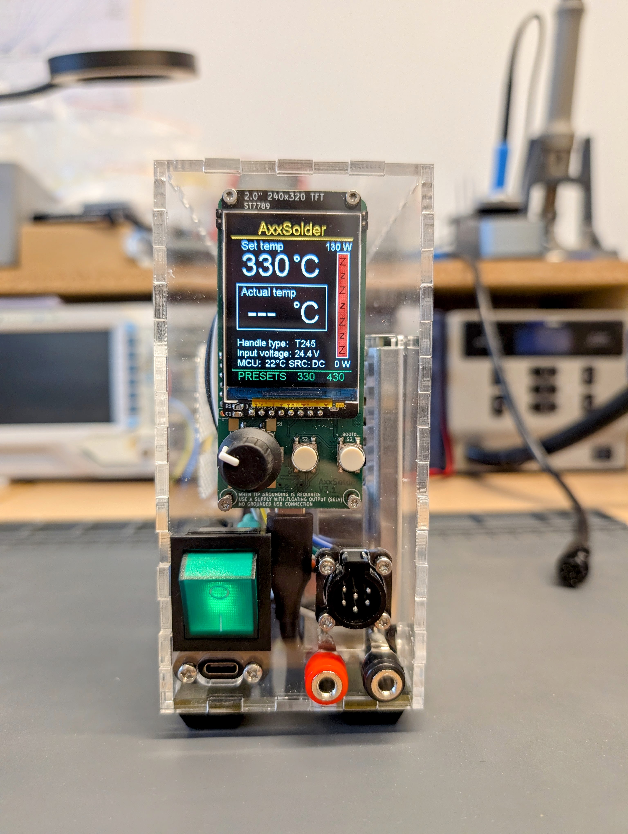
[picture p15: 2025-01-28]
CAD/Alternative_enclosures_and_designs/AxxSolder-LaborStation/AxxSolderFront.jpg

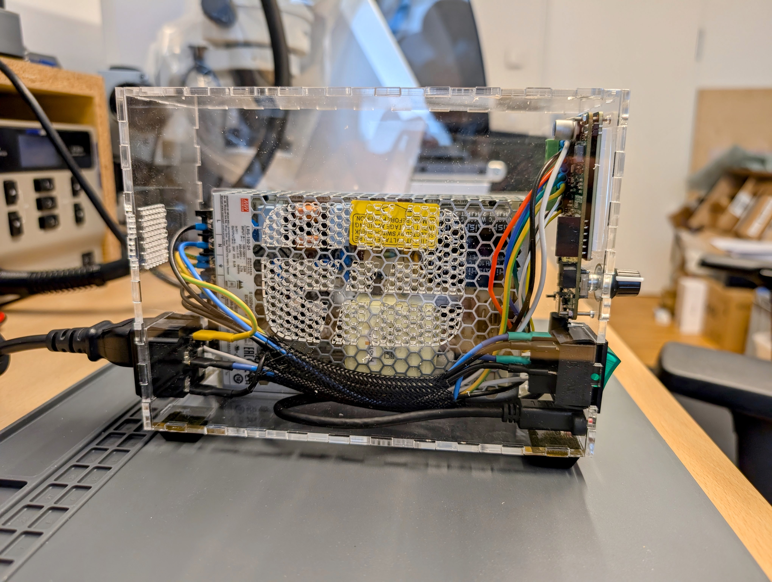
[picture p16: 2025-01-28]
CAD/Alternative_enclosures_and_designs/AxxSolder-LaborStation/AxxSolderSide.jpg

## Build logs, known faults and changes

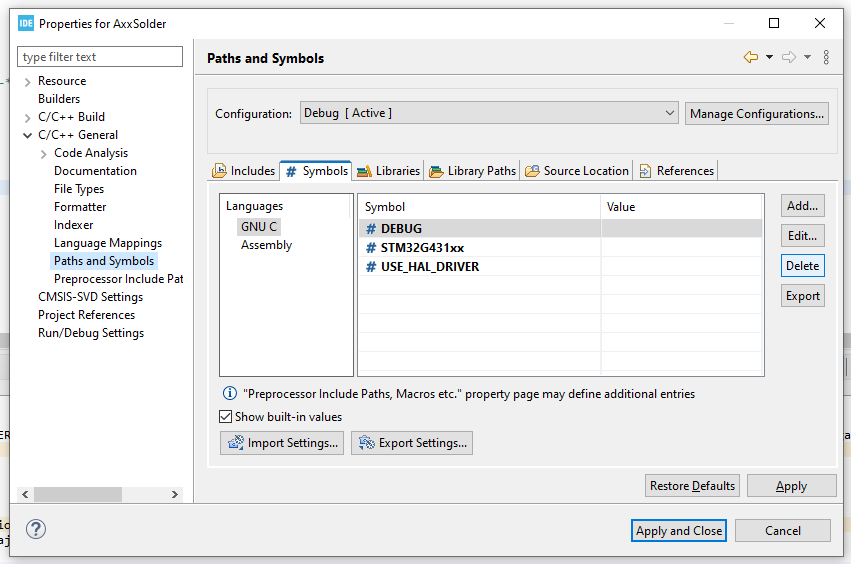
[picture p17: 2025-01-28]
Other/Do not define DEBUG.png

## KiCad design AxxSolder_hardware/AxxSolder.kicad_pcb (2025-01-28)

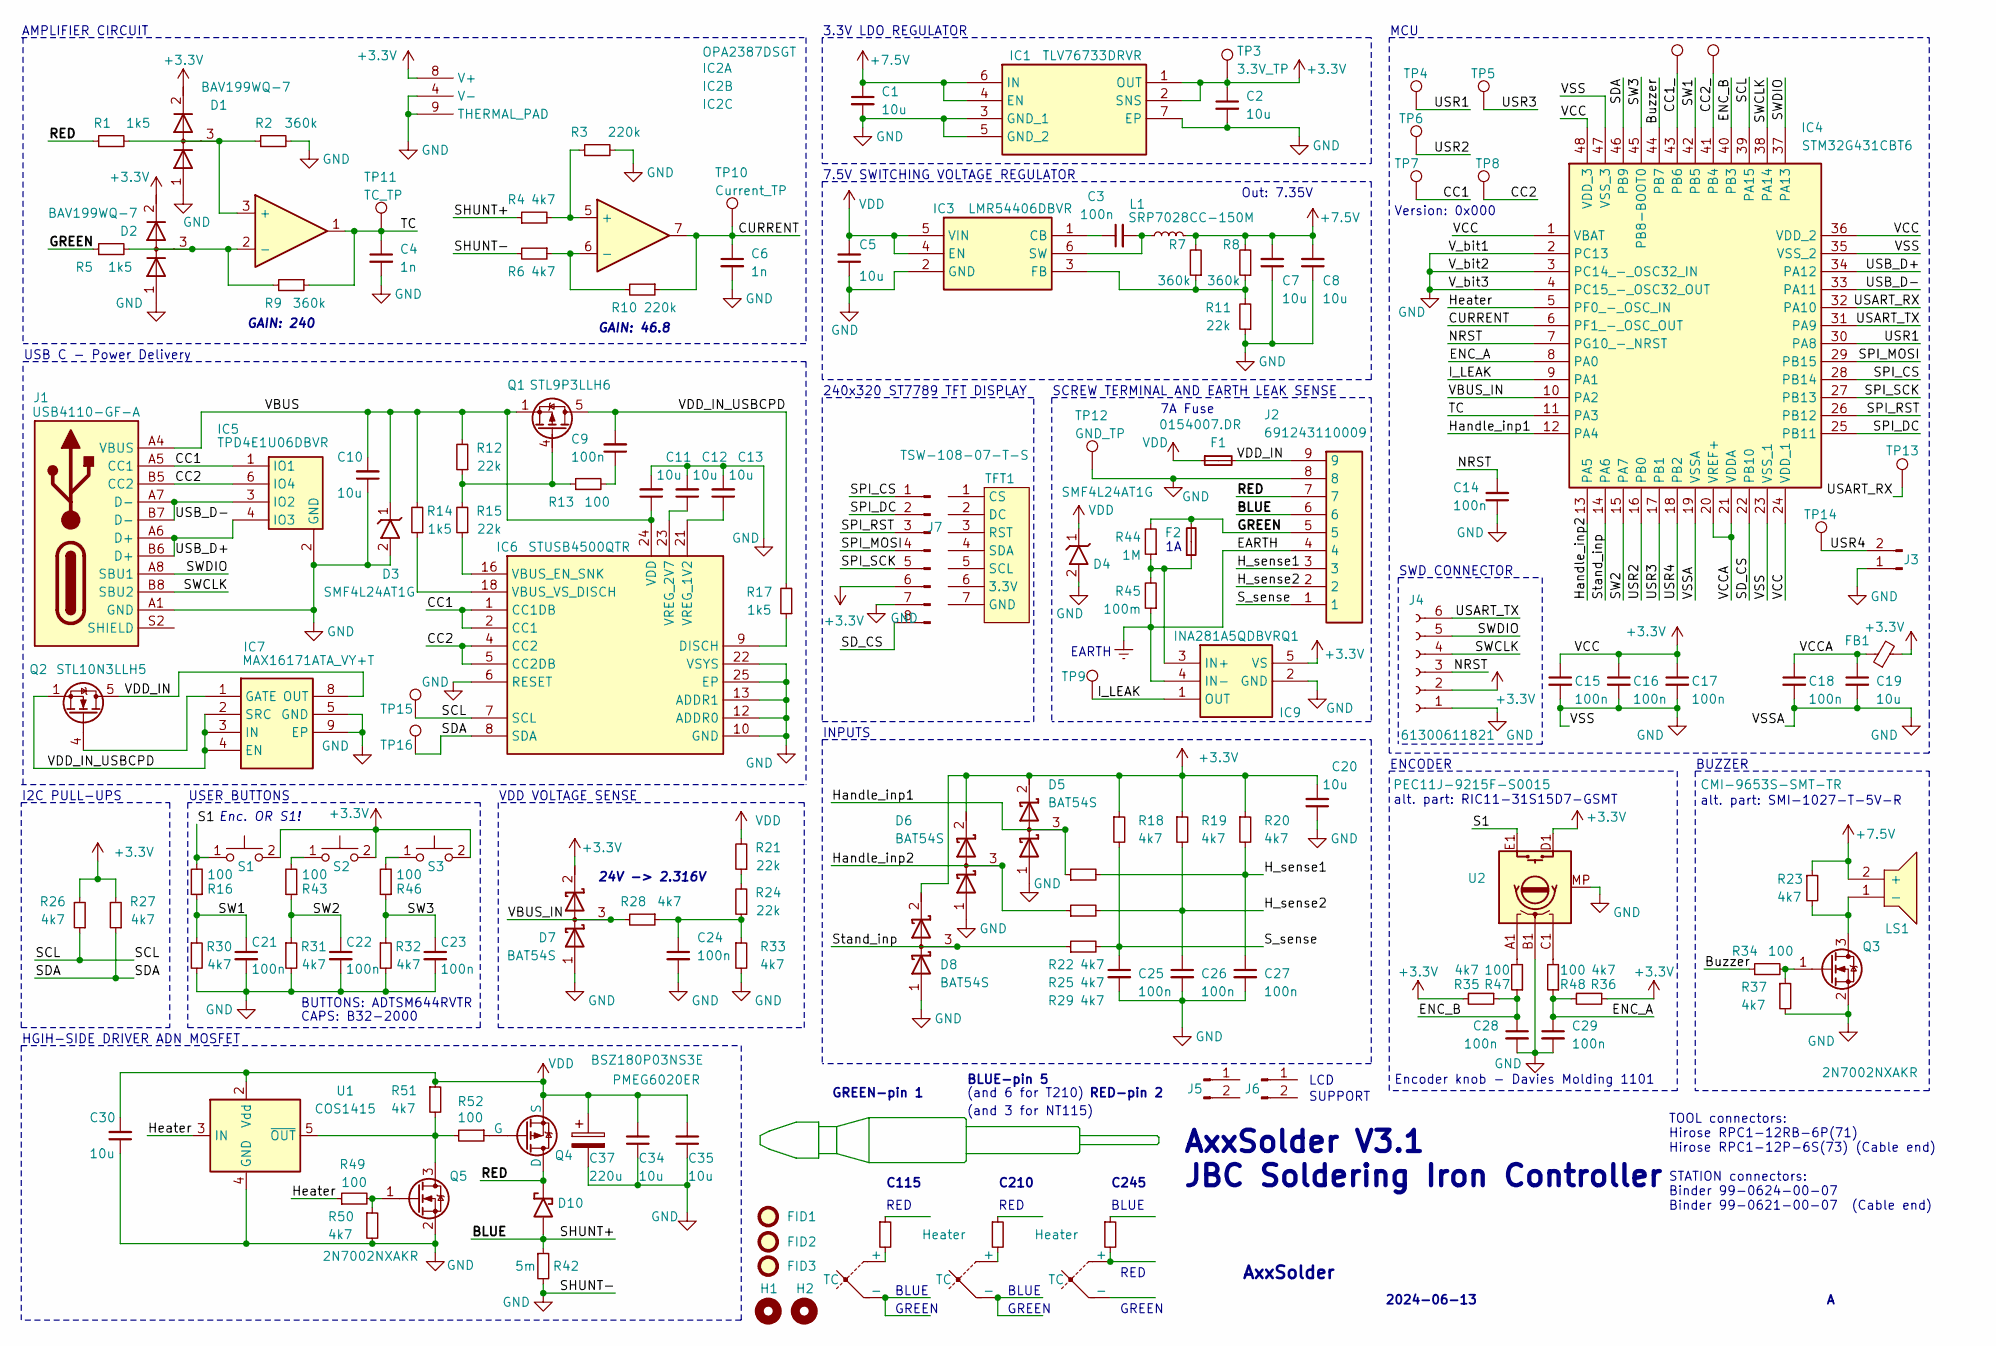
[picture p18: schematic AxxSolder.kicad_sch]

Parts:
C1, C2, C5, C7, C8, C10, C11, C12, C13, C19, C20, C30, C34, C35: 10u; C_0603_1608Metric; Manufacturer_Part_Number GRM188R6YA106MA73J; Mouser Part Number 81-GRM188R6YA106MA3J
C3, C9, C14, C15, C16, C17, C18, C21, C22, C23, C24, C25, C26, C27, C28, C29: 100n; C_0603_1608Metric; Manufacturer_Part_Number C0603C104J5RACTU; Mouser Part Number 80-C0603C104J5R
C4, C6: 1n; C_0603_1608Metric; Manufacturer_Part_Number C0603C102K3GAC; Mouser Part Number 80-C0603C102K3G
C37: 220u; CAPAE830X1050N; Mouser Part Number 80-EEV227M035A9MAA
D1, D2: BAV199WQ-7; SOT65P210X110-3N; Mouser Part Number 621-BAV199WQ-7
D3, D4: SMF4L24AT1G; SODFL3619X98N; Mouser Part Number 576-SMF4L24AT1G
D5, D6, D7, D8: BAT54S; SOT95P230X110-3N; Manufacturer_Part_Number BAT54S,215; Mouser Part Number 771-BAT54S-T/R
D10: PMEG6020ER; PMEG6020ER115; Mouser Part Number 771-PMEG6020ER-115
F1: 0154007.DR; 0154100DR; Mouser Part Number 576-0154007.DR
F2: SF-2410FP100W-2; SF2410FP100W2; Mouser Part Number 652-SF-2410FP100W-2
FB1: BLM18HE601SN1D; R_0603_1608Metric; Mouser Part Number 81-BLM18HE601SN1D
FID1, FID2, FID3: Fiducial; Fiducial_0.75mm_Mask1.5mm
H1, H2: MountingHole; MountingHole_2.5mm
IC1: TLV76733DRVR; SON65P200X200X80-7N; Mouser Part Number 595-TLV76733DRVR
IC2: OPA2387DSGT; VSSOP-8_3x3mm_P0.65mm; Mouser Part Number 595-OPA2387DSGT
IC3: LMR54406DBVR; SOT95P280X145-6N; Mouser Part Number 595-LMR54406DBVR
IC4: STM32G431CBT6; QFP50P900X900X160-48N; Mouser Part Number 511-STM32G431CBT6
IC5: TPD4E1U06DBVR; SOT95P280X145-6N; Mouser Part Number 595-TPD4E1U06DBVR
IC6: STUSB4500QTR; QFN50P400X400X100-25N-D; Mouser Part Number 511-STUSB4500QTR
IC7: MAX16171ATA_VY+T; SON50P300X200X80-9N; Mouser Part Number 700-MAX16171ATA/VY+T
IC9: INA281A5QDBVRQ1; SOT95P280X145-5N; Mouser Part Number 595-INA281A5QDBVRQ1
J1: USB4110-GF-A; USB4110GFA; Mouser Part Number 640-USB4110-GF-A
J2: 691243110009; Mouser Part Number 710-691243110009
J3: TSW-102-07-T-S; PinHeader_1x02_P2.54mm_Vertical; Mouser Part Number 200-TSW10207TS
J4: 61300611821; RHDR6W97P0X254_1X6_1574X250X865P; Mouser Part Number 710-61300611821
J5, J6: TSW-102-07-T-S; TSW-102-XX-YY-S; Mouser Part Number 200-TSW10207TS
J7: TSW-108-07-T-S; TSW-108-XX-YY-S; Mouser Part Number 200-TSW10807TS
L1: SRP7028CC-150M; INDPM7366X300N; Mouser Part Number 652-SRP7028CC-150M
LS1: CMI-9653S-SMT-TR; CMI9653SSMTTR; Mouser Part Number 490-CMI-9653S-SMT-TR
Q1: STL9P3LLH6; Mouser Part Number 511-STL9P3LLH6
Q2: STL10N3LLH5; Mouser Part Number 511-STL10N3LLH5
Q3, Q5: 2N7002NXAKR; SOT95P230X110-3N; Manufacturer_Part_Number 2N7002NXAKR; Mouser Part Number 771-2N7002NXAKR
Q4: BSZ180P03NS3E; TDSON-8-1
R1, R5, R14, R17: 1k5; R_0603_1608Metric; Manufacturer_Part_Number ERJ-H3ED1501V; Mouser Part Number 667-ERJ-H3ED1501V
R2, R7, R8, R9: 360k; R_0603_1608Metric; Manufacturer_Part_Number ERJ-3RED3603V; Mouser Part Number 667-ERJ-3RED3603V
R3, R10: 220k; R_0603_1608Metric; Manufacturer_Part_Number ERJ-3RED2203V; Mouser Part Number 667-ERJ-3RED2203V
R4, R6, R18, R19, R20, R22, R23, R25, R26, R27, R28, R29, R30, R31, R32, R33, R35, R36, R37, R50: 4k7; R_0603_1608Metric; Manufacturer_Part_Number ERJ-3RBD4701V; Mouser Part Number 667-ERJ-3RBD4701V
R11, R12, R15, R21, R24: 22k; R_0603_1608Metric; Manufacturer_Part_Number ERJ-UP3J223V; Mouser Part Number 667-ERJ-UP3J223V
R13, R16, R34, R43, R46, R47, R48, R49: 100; R_0603_1608Metric; Manufacturer_Part_Number ERJ-P03F1000V; Mouser Part Number 667-ERJ-P03F1000V
R39, R40: Heater
R41: Heater 2 OHM
R42: 5m; RESC6432X89N; Mouser Part Number 71-WSLP25125L000FEA
R44: 1M; R_0805_2012Metric; Manufacturer_Part_Number ERJ-6GEYJ105V; Mouser Part Number 667-ERJ-6GEYJ105V
R45: 100m; R_0805_2012Metric; Manufacturer_Part_Number ERJ-6DSFR10V; Mouser Part Number 667-ERJ-6DSFR10V
R51: 4k7; R_1210_3225Metric_Pad1.30x2.65mm_HandSolder; Manufacturer_Part_Number ERJ-3RBD4701V; Mouser Part Number 667-ERJ-3RBD4701V
R52: 100; R_0603_1608Metric; Manufacturer_Part_Number ERJ-3RBD4701V; Mouser Part Number 667-ERJ-3RBD4701V
S1, S2, S3: ADTSM644RVTR; Mouser Part Number 642-ADTSM644RVTR
TC1, TC2, TC3: TC
TFT1: Adafruit_240x320_TFT; Manufacturer_Part_Number 4311; Mouser Part Number 485-4311
TP1, TP2, TP4, TP5, TP6, TP7, TP8, TP14, TP15, TP16: DIAG_TP; TestPoint_Pad_D1.0mm
TP3: 3.3V_TP; TestPoint_Pad_D1.0mm
TP9, TP10: Current_TP; TestPoint_Pad_D1.0mm
TP11: TC_TP; TestPoint_Pad_D1.0mm
TP12: GND_TP; TestPoint_Pad_D1.0mm
TP13: DIAG_TP; TSW-101-XX-YY-S
U1: COS1415; SOT-23-5
U2: PEC11J-9215F-S0015; PEC11J9215FS0015; Mouser Part Number 652-PEC11J9215FS0015

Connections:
+3.3V: C2.1, C15.1, C16.1, C17.1, C20.2, D1.2, D2.2, D5.2 (K), D6.2 (K), D7.2 (K), D8.2 (K), FB1.2, IC1.1 (OUT), IC1.2 (SNS), IC2.8 (V+), IC4.1 (VBAT), IC4.24 (VDD_1), IC4.36 (VDD_2), IC4.48 (VDD_3), IC9.5 (VS), J4.2, J7.6, R18.1, R19.1, R20.1, R26.2, R27.2, R35.2, R36.1, S1.2, S2.2, S3.2, TP3.1, U2.D1
+7.5V: C1.1, C7.2, C8.2, IC1.4 (EN), IC1.6 (IN), L1.2, LS1.2 (+), R7.2, R8.2, R23.1
/BLUE: D10.2, J2.6, R4.1, R42.1
/Buzzer: IC4.44 (PB7), R34.1
/CC1: IC5.1 (IO1), IC6.1 (CC1DB), IC6.2 (CC1), J1.A5 (CC1), TP7.1
/CC1_: IC4.43 (PB6), TP1.1
/CC2: IC5.6 (IO4), IC6.4 (CC2), IC6.5 (CC2DB), J1.B5 (CC2), TP8.1
/CC2_: IC4.41 (PB4), TP2.1
/CURRENT: C6.1, IC2.7, IC4.6 (PF1_-_OSC_OUT), R10.1, TP10.1
/ENC_A: C29.1, IC4.8 (PA0), R36.2, R48.1
/ENC_B: C28.1, IC4.40 (PB3), R35.1, R47.1
/GREEN: F2.2, J2.5, R5.1, R44.2
/H_sense1: C27.1, J2.3, R20.2, R22.2
/H_sense2: C26.1, J2.2, R19.2, R25.2
/Handle_inp1: D5.3 (common), IC4.12 (PA4), R22.1
/Handle_inp2: D6.3 (common), IC4.13 (PA5), R25.1
/Heater: IC4.5 (PF0_-_OSC_IN), R49.1, U1.3 (IN)
/I_LEAK: IC4.9 (PA1), IC9.1 (OUT), TP9.1
/NRST: C14.2, IC4.7 (PG10_-_NRST), J4.3
/RED: D10.1, J2.7, Q4.5 (D), R1.1
/S1: R16.2, S1.1, U2.E1
/SCL: IC4.39 (PA15), IC6.7 (SCL), R26.1, TP15.1
/SDA: IC4.46 (PB9), IC6.8 (SDA), R27.1, TP16.1
/SD_CS: IC4.22 (PB10), J7.8
/SPI_CS: IC4.28 (PB14), J7.1
/SPI_DC: IC4.25 (PB11), J7.2
/SPI_MOSI: IC4.29 (PB15), J7.4
/SPI_RST: IC4.26 (PB12), J7.3
/SPI_SCK: IC4.27 (PB13), J7.5
/SW1: C21.1, IC4.42 (PB5), R16.1, R30.1
/SW2: C22.1, IC4.15 (PA7), R31.1, R43.1
/SW3: C23.1, IC4.45 (PB8-BOOT0), R32.1, R46.1
/SWCLK: IC4.38 (PA14), J1.B8 (SBU2), J4.4
/SWDIO: IC4.37 (PA13), J1.A8 (SBU1), J4.5
/S_sense: C25.1, J2.1, R18.2, R29.2
/Stand_inp: D8.3 (common), IC4.14 (PA6), R29.1
/TC: C4.1, IC2.1, IC4.11 (PA3), R9.1, TP11.1
/USART_RX: IC4.32 (PA10), TP13.1
/USART_TX: IC4.31 (PA9), J4.6
/USB_D+: IC4.34 (PA12), IC5.4 (IO3), J1.A6 (D+), J1.B6 (D+)
/USB_D-: IC4.33 (PA11), IC5.3 (IO2), J1.A7 (D-), J1.B7 (D-)
/USR1: IC4.30 (PA8), TP4.1
/USR2: IC4.16 (PB0), TP6.1
/USR3: IC4.17 (PB1), TP5.1
/USR4: IC4.18 (PB2), J3.2, TP14.1
/VBUS: C10.2, C11.1, D3.1 (K), IC6.24 (VDD), J1.A4 (VBUS), J1.A9 (VBUS), J1.B4 (VBUS), J1.B9 (VBUS), Q1.1 (S), R12.2, R14.2
/VBUS_IN: D7.3 (common), IC4.10 (PA2), R28.2
/VCCA: C18.1, C19.1, FB1.1, IC4.20 (VREF+), IC4.21 (VDDA)
/VDD_IN: F1.2, IC7.8 (OUT), J2.9, Q2.5 (D)
/VDD_IN_USBCPD: C9.2, IC7.2 (SRC), IC7.3 (IN), IC7.4 (EN), Q1.5 (D), Q2.1 (S), R17.2
Earth: IC9.4 (IN-), J2.4, R45.1
GND: C1.2, C2.2, C4.2, C5.1, C6.2, C7.1, C8.1, C10.1, C11.2, C12.2, C13.2, C14.1, C15.2, C16.2, C17.2, C18.2, C19.2, C20.1, C21.2, C22.2, C23.2, C24.2, C25.2, C26.2, C27.2, C28.2, C29.2, C30.1, C34.1, C35.1, C37.2, D1.1, D2.1, D3.2 (A), D4.2 (A), D5.1 (A), D6.1 (A), D7.1 (A), D8.1 (A), IC1.3 (GND_1), IC1.5 (GND_2), IC1.7 (EP), IC2.4 (V-), IC2.9 (THERMAL_PAD), IC3.2 (GND), IC4.2 (PC13), IC4.3 (PC14_-_OSC32_IN), IC4.4 (PC15_-_OSC32_OUT), IC4.19 (VSSA), IC4.23 (VSS_1), IC4.35 (VSS_2), IC4.47 (VSS_3), IC5.2 (GND), IC6.6 (RESET), IC6.10 (GND), IC6.12 (ADDR0), IC6.13 (ADDR1), IC6.22 (VSYS), IC6.25 (EP), IC7.5 (GND), IC7.9 (EP), IC9.2 (GND), J1.A1 (GND), J1.A12 (GND), J1.B1 (GND), J1.B12 (GND), J2.8, J3.1, J4.1, J7.7, Q3.2 (S), Q5.2 (S), R2.2, R3.2, R6.2, R11.1, R30.2, R31.2, R32.2, R33.2, R37.2, R42.2, R50.2, TP12.1, U1.4 (GND), U2.B1, U2.MP
unnamed: C9.1, R13.2
unnamed: C24.1, R24.1, R28.1, R33.1
unnamed: D1.3, IC2.3 (+), R1.2, R2.1
unnamed: D2.3, IC2.2 (-), R5.2, R9.2
unnamed: IC2.5 (+), R3.1, R4.2
unnamed: IC2.6 (-), R6.1, R10.2
unnamed: C3.1, IC3.1 (CB)
unnamed: IC3.3 (FB), R7.1, R8.1, R11.2
unnamed: C3.2, IC3.6 (SW), L1.1
unnamed: IC6.9 (DISCH), R17.1
unnamed: IC6.16 (VBUS_EN_SNK), R15.1
unnamed: IC6.18 (VBUS_VS_DISCH), R14.1
unnamed: C13.1, IC6.21 (VREG_1V2)
unnamed: C12.1, IC6.23 (VREG_2V7)
unnamed: IC7.1 (GATE), Q2.4 (G)
unnamed: F2.1, IC9.3 (IN+), R44.1, R45.2
unnamed: LS1.1 (-), Q3.3 (D), R23.2
unnamed: Q1.4 (G), R12.1, R13.1, R15.2
unnamed: Q3.1 (G), R34.2, R37.1
unnamed: Q4.4 (G), R52.1
unnamed: Q5.3 (D), R51.2, R52.2, U1.5 (~OUT)
unnamed: Q5.1 (G), R49.2, R50.1
unnamed: R21.1, R24.2
unnamed: R39.2, TC1.1 (+)
unnamed: R40.2, TC2.1 (+)
unnamed: R41.2, TC3.1 (+)
unnamed: R43.2, S2.1
unnamed: R46.2, S3.1
unnamed: R47.2, U2.A1
unnamed: R48.2, U2.C1
VDD: C5.2, C30.2, C34.2, C35.2, C37.1, D4.1 (K), F1.1, IC3.4 (EN), IC3.5 (VIN), Q4.1 (S), R21.2, R51.1, U1.2 (Vdd)

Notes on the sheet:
Version: 0x000
USER BUTTONS
C115
7A Fuse
Encoder knob - Davies Molding 1101
USB C - Power Delivery
BUTTONS: ADTSM644RVTR
Enc. OR S1!
MCU
CAPS: B32-2000
GREEN
(and 3 for NT115)
GREEN-pin 1
RED
LCD
alt. part: SMI-1027-T-5V-R
(and 6 for T210)
SCREW TERMINAL AND EARTH LEAK SENSE
AMPLIFIER CIRCUIT
24V -> 2.316V
VDD VOLTAGE SENSE
C245
ENCODER
SWD CONNECTOR
BLUE
BLUE-pin 5
2024-06-13
BUZZER
7.5V SWITCHING VOLTAGE REGULATOR
AxxSolder V3.1 JBC Soldering Iron Controller
TOOL connectors: Hirose RPC1-12RB-6P(71) Hirose RPC1-12P-6S(73) (Cable end) STATION connectors: Binder 99-0624-00-07 Binder 99-0621-00-07 (Cable end)
C210
INPUTS
EARTH
HGIH-SIDE DRIVER ADN MOSFET
AxxSolder
RED-pin 2
RED
Out: 7.35V
I2C PULL-UPS

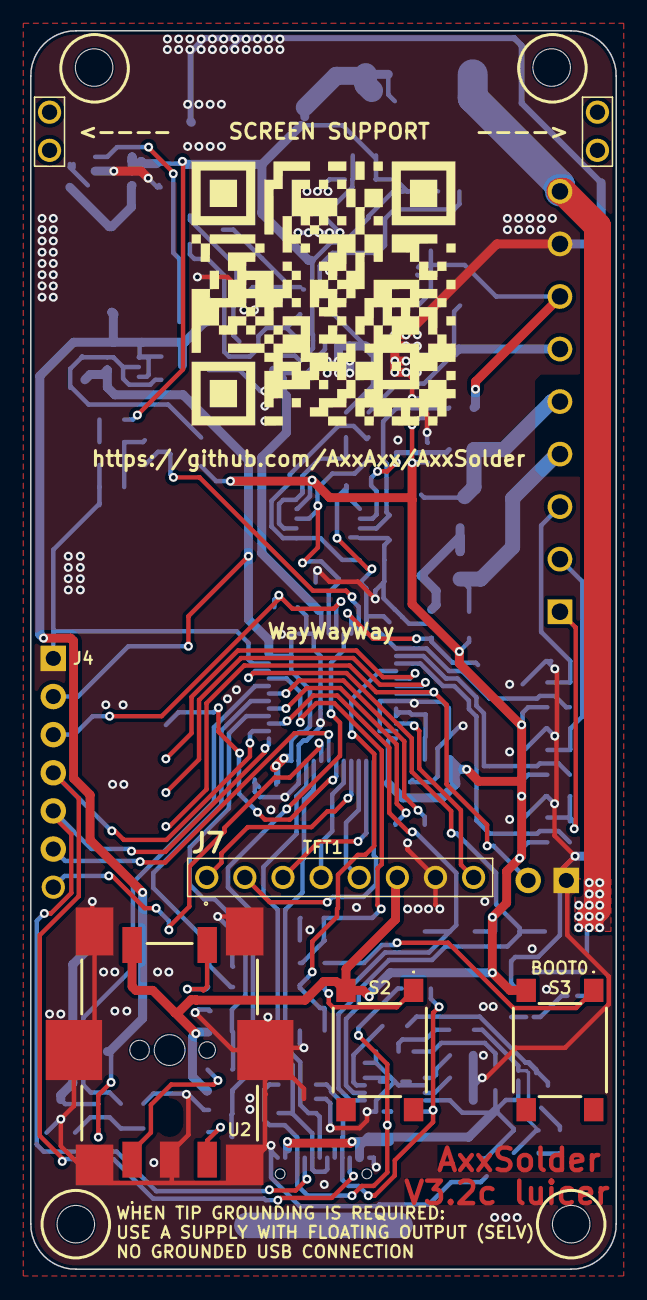
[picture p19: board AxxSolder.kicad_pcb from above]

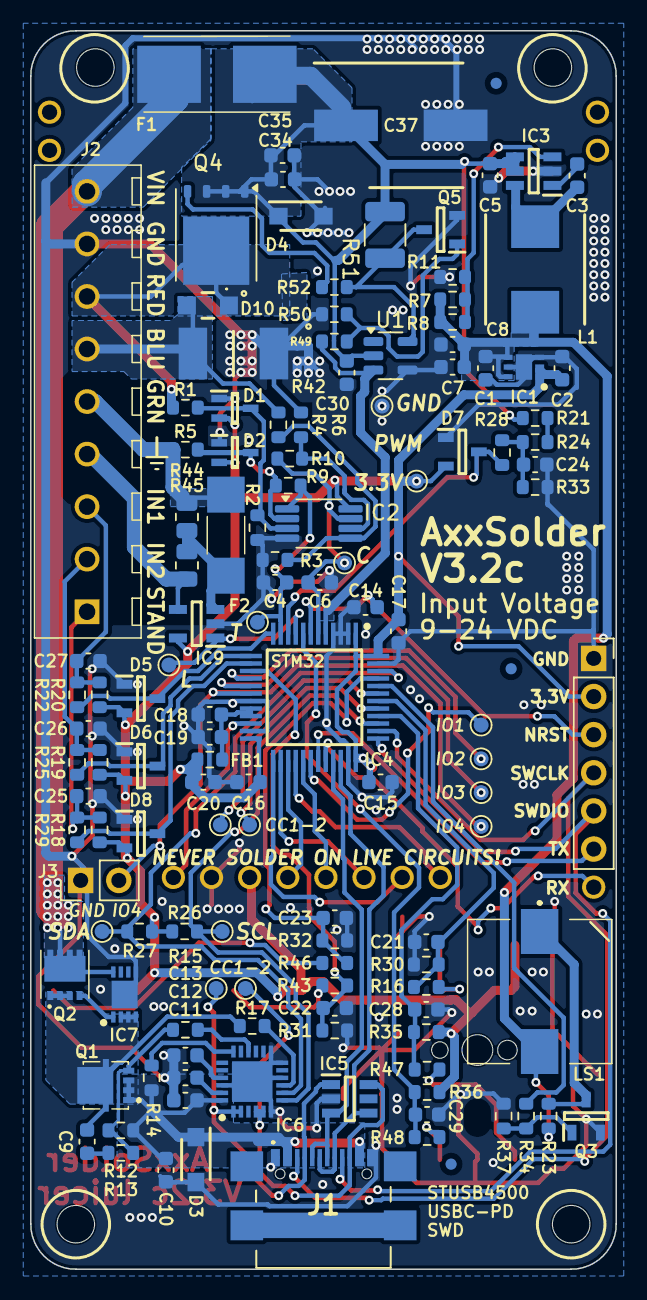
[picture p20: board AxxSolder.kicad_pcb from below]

Board: 2 copper layers, 39.0 x 82.5 mm, 141 parts (133 on the bottom side), 80 nets.

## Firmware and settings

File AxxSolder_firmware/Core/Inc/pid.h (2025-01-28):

#ifndef INC_PID_H
#define INC_PID_H

/* Include */
#include <stdint.h>
#include <string.h>
#include "main.h"
#include "stm32g4xx_hal.h"       /* Import HAL library */
#include <math.h>

#define DEFAULT_SAMPLE_TIME_MS 100
#define DEFAULT_PWM_MAX 100

/* PID Mode */
typedef enum{
	_PID_MODE_MANUAL    = 0,
	_PID_MODE_AUTOMATIC = 1
}PIDMode_TypeDef;

/* PID Control direction */
typedef enum{
	_PID_CD_DIRECT  = 0,
	_PID_CD_REVERSE = 1
}PIDCD_TypeDef;

/* PID Structure */
typedef struct{

	PIDMode_TypeDef InAuto;
	PIDCD_TypeDef   ControllerDirection;

	uint32_t        LastTime;
	uint32_t        SampleTime;

	uint32_t        updateOnEveryCall;

	float          DispKp;
	float          DispKi;
	float          DispKd;

	float          Kp;
	float          Ki;
	float          Kd;

	float          DispKp_part;
	float          DispKi_part;
	float          DispKd_part;

	float          *MyInput;
	float          *MyOutput;
	float          *MySetpoint;

	float          OutputSum;
	float          LastInput;

	float          OutMin;
	float          OutMax;

	float          IMin;
	float          IMax;

	float			IminError;

	float			NegativeErrorIgainMultiplier;
	float			NegativeErrorIgainBias;

}PID_TypeDef;

/* Init */
void PID_Init(PID_TypeDef *uPID);

void PID(PID_TypeDef *uPID, float *Input, float *Output, float *Setpoint, float Kp, float Ki, float Kd, PIDCD_TypeDef ControllerDirection);

/* Function to clamp d between the limits min and max */
float float_clamp(float d, float min, float max);

/* Function to check if clamping will occur */
uint8_t check_clamping(float d, float min, float max);

/* Computing */
uint8_t PID_Compute(PID_TypeDef *uPID);

/* PID Limits */
void PID_SetOutputLimits(PID_TypeDef *uPID, float Min, float Max);

/* PID I-windup Limits */
void PID_SetILimits(PID_TypeDef *uPID, float Min, float Max);

/* Minimum error where I is added */
void PID_SetIminError(PID_TypeDef *uPID, float IminError);

/* Set the I gain multiplier for negative error*/
void PID_SetNegativeErrorIgainMult(PID_TypeDef *uPID, float NegativeErrorIgainMultiplier, float NegativeErrorIgainBias);

/* PID Tunings */
void PID_SetTunings(PID_TypeDef *uPID, float Kp, float Ki, float Kd);

/* PID Direction */
void          PID_SetControllerDirection(PID_TypeDef *uPID, PIDCD_TypeDef Direction);
PIDCD_TypeDef PID_GetDirection(PID_TypeDef *uPID);

/* PID Sampling */
void PID_SetSampleTime(PID_TypeDef *uPID, int32_t NewSampleTime, int32_t updateOnCall);

void PID_SetMode(PID_TypeDef *uPID, PIDMode_TypeDef Mode);

/* Get Tunings Param */
float PID_GetKp(PID_TypeDef *uPID);
float PID_GetKi(PID_TypeDef *uPID);
float PID_GetKd(PID_TypeDef *uPID);

/* Get current contributions */
float PID_GetPpart(PID_TypeDef *uPID);
float PID_GetIpart(PID_TypeDef *uPID);
float PID_GetDpart(PID_TypeDef *uPID);

#endif

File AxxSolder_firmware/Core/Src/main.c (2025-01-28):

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
/* Includes ------------------------------------------------------------------*/
#include "main.h"

/* USER CODE BEGIN Includes */
#include "lcd.h"
#include "string.h"
#include "pid.h"
#include "moving_average.h"
#include "hysteresis.h"
#include "type_packers.h"
#include "flash.h"
#include "stusb4500.h"
#include "buzzer.h"
#include "debug.h"
#include <math.h>
#include <stdio.h>
#include <float.h>
//#include "usbd_cdc_if.h"
/* USER CODE END Includes */

/* USER CODE BEGIN PTD */
uint8_t fw_version_major =  3;
uint8_t fw_version_minor =  3;
uint8_t fw_version_patch =  1;

//#define PID_TUNING
DEBUG_VERBOSITY_t debugLevel = DEBUG_INFO;

/* Cartridge type specific PID parameters */
#define KP_NT115 					5
#define KI_NT115 					2
#define KD_NT115 					0.3
#define MAX_I_NT115 				300

#define KP_T210 					7
#define KI_T210 					4
#define KD_T210 					0.3
#define MAX_I_T210 					300

#define KP_T245 					8
#define KI_T245 					2
#define KD_T245 					0.5
#define MAX_I_T245 					300

/* General PID parameters */
#define PID_MAX_OUTPUT 500
#define PID_UPDATE_INTERVAL 25
#define PID_ADD_I_MIN_ERROR 75
float PID_NEG_ERROR_I_MULT = 7;
float PID_NEG_ERROR_I_BIAS = 1;

/* Timing constants */
uint32_t previous_millis_display = 0;
uint32_t interval_display = 40;

uint32_t previous_millis_debug = 0;
uint32_t interval_debug = 50;

uint32_t previous_millis_heating_halted_update = 0;
uint32_t interval_heating_halted_update = 500;

uint32_t previous_millis_left_stand = 0;

uint32_t previous_millis_standby = 0;

uint32_t previous_measure_current_update = 0;
uint32_t interval_measure_current = 250;

uint32_t previous_sensor_update_high_update = 0;
uint32_t interval_sensor_update_high_update = 10;

uint32_t previous_sensor_update_low_update = 0;
uint32_t interval_sensor_update_low_update = 100;

/* Handles */
enum handles {
	NT115,
	T210,
	T245
} attached_handle;

/* power sources */
typedef enum {
	POWER_DC,
	POWER_USB,
	POWER_BAT //Future feature
}power_source_t;
power_source_t power_source = POWER_DC;

/* states for runtime switch */
typedef enum {
    RUN,
	STANDBY,
	SLEEP,
	EMERGENCY_SLEEP,
	HALTED
} mainstates;

/* states for cartridge */
typedef enum {
	ATTACHED,
	DETACHED
} cartridge_state_t;
cartridge_state_t cartridge_state = ATTACHED;
cartridge_state_t previous_cartridge_state = ATTACHED;

uint8_t sleep_state_written_to_LCD = 0;
uint8_t standby_state_written_to_LCD = 0;

/* Custom tuning parameters */
float Kp_tuning = 0;
float Ki_tuning = 0;
float Kd_tuning = 0;
float temperature_tuning = 100;
float PID_MAX_I_LIMIT_tuning = 0;

/* Allow use of custom temperatue, used for tuning */
uint8_t custom_temperature_on = 0;

/* Buffer for UART print */
char UART_buffer[40];

/* Buffer for UART print */
char DISPLAY_buffer[40];

/* ADC Buffer */
#define ADC1_BUF_LEN 57 //3*19
uint16_t ADC1_BUF[ADC1_BUF_LEN];

/* RAW ADC from current measurement */
uint16_t current_raw = 0;

/* Thermocouple temperature */
float TC_temp = 0;

/* Flag to indicate that startup sequence is done */
uint8_t startup_done = 0;

/* Flag to indicate that settings menu is active */
uint8_t settings_menu_active = 0;

/* Variables for thermocouple outlier detection */
float TC_temp_from_ADC = 0;
float TC_temp_from_ADC_previous = 0;
float TC_temp_from_ADC_diff = 0;
uint16_t TC_outliers_detected = 0;
#define TC_OUTLIERS_THRESHOLD 300

/* Max allowed tip temperature */
#define EMERGENCY_SHUTDOWN_TEMPERATURE 490

/* Constants for scaling input voltage ADC value*/
#define VOLTAGE_COMPENSATION 0.00840442388
#define CURRENT_COMPENSATION 0.002864

/* Constants for scaling power in W to correct duty cycle */
#define POWER_CONVERSION_FACTOR 0.123

/* Min allowed bus voltage and power */
#define MIN_BUSVOLTAGE 8.0
#define MIN_BUSPOWER 8.0
#define USB_PD_POWER_REDUCTION_FACTOR 1.0

/* Max allowed power per handle type */
#define NT115_MAX_POWER 22
#define T210_MAX_POWER 	65
#define T245_MAX_POWER 	130
#define MAX_POWER 		150

/* Min and Max selectable values */
#define MIN_SELECTABLE_TEMPERATURE 20
#define MAX_SELECTABLE_TEMPERATURE 450

/* TC Compensation constants */
#define TC_COMPENSATION_X2_NT115 (5.1026665462522864e-05)
#define TC_COMPENSATION_X1_NT115 0.42050803230712813
#define TC_COMPENSATION_X0_NT115 20.14538589052425

#define TC_COMPENSATION_X2_T210 (4.223931712905644e-06)
#define TC_COMPENSATION_X1_T210 0.31863796444354214
#define TC_COMPENSATION_X0_T210 20.968033870812942

#define TC_COMPENSATION_X2_T245 (-4.735112838956741e-07)
#define TC_COMPENSATION_X1_T245 0.11936452029674384
#define TC_COMPENSATION_X0_T245 23.777399955382318

/* Constants for internal MCU temperture */
#define V30 		0.76 			// from datasheet
#define VSENSE 		(3.3/4096.0) 	// VSENSE value
#define Avg_Slope 	0.0025 			// 2.5mV from datasheet

/* Largest delta temperature before detecting a faulty or missing cartridge */
#define MAX_TC_DELTA_FAULTDETECTION 25

/* Define time for long button press */
#define BTN_LONG_PRESS 15 //*50ms (htim16 interval) --> 15 = 750ms

/* Button flags */
volatile uint8_t SW_ready = 1;
volatile uint8_t SW_1_pressed = 0;
volatile uint8_t SW_2_pressed = 0;
volatile uint8_t SW_3_pressed = 0;
volatile uint8_t SW_1_pressed_long = 0;
volatile uint8_t SW_2_pressed_long = 0;
volatile uint8_t SW_3_pressed_long = 0;

/* UART send buffers */
#define MAX_BUFFER_LEN 250
uint8_t UART_transmit_buffer[MAX_BUFFER_LEN];
uint8_t UART_packet_index = 0;
uint8_t UART_packet_length = 0;

/* Struct to hold sensor values */
struct sensor_values_struct {
	float set_temperature;
	float thermocouple_temperature;
	float thermocouple_temperature_previous;
	float thermocouple_temperature_filtered;
	float requested_power;
	float requested_power_filtered;
	float bus_voltage;
	float heater_current;
	uint16_t leak_current;
	float mcu_temperature;
	float in_stand;
	float handle1_sense;
	float handle2_sense;
	mainstates current_state;
	mainstates previous_state;
	float max_power_watt;
	float USB_PD_power_limit;
};

/* Struct to hold sensor values */
struct sensor_values_struct sensor_values  = {.set_temperature = 0.0,
        									.thermocouple_temperature = 0.0,
        									.thermocouple_temperature_previous = 0.0,
											.thermocouple_temperature_filtered = 0,
											.requested_power = 0.0,
											.requested_power_filtered = 0.0,
											.bus_voltage = 0.0,
											.heater_current = 0,
											.leak_current = 0,
											.mcu_temperature = 0.0,
											.in_stand = 0.0,
											.handle1_sense  = 0.0,
											.handle2_sense  = 0.0,
											.current_state = SLEEP,
											.previous_state = SLEEP,
											.max_power_watt = 0,
											.USB_PD_power_limit = DBL_MAX};

/* Struct to hold flash values */
Flash_values flash_values;
Flash_values default_flash_values = {.startup_temperature = 330,
											.temperature_offset = 0,
											.standby_temp = 150,
											.standby_time = 10,
											.emergency_time = 30,
											.buzzer_enabled = 1,
											.preset_temp_1 = 330,
											.preset_temp_2 = 430,
											.GPIO4_ON_at_run = 0,
											.screen_rotation = 2,
											.power_limit = 0,
											.current_measurement = 1,
											.startup_beep = 1,
											.deg_celsius = 1,
											.temp_cal_100 = 100,
											.temp_cal_200 = 200,
											.temp_cal_300 = 300,
											.temp_cal_350 = 350,
											.temp_cal_400 = 400,
											.temp_cal_450 = 450,
											.serial_debug_print = 0,
											.displayed_temp_filter = 5,
											.startup_temp_is_previous_temp = 0,
											.three_button_mode = 0};

/* List of names for settings menu */
#define menu_length 27
char menu_names[menu_length][30] = { "Startup Temp °C    ",
							"Temp Offset °C      ",
							"Standby Temp °C   ",
							"Standby Time [min]  ",
							"Sleep Time [min]    ",
							"Buzzer Enabled      ",
							"Preset Temp 1 °C   ",
							"Preset Temp 2 °C   ",
							"GPIO4 ON at run    ",
							"Screen Rotation     ",
							"Limit Power [W]     ",
							"I Measurement       ",
							"Startup Beep         ",
							"Temp in Celsius     ",
							"Temp cal 100         ",
							"Temp cal 200         ",
							"Temp cal 300         ",
							"Temp cal 350         ",
							"Temp cal 400         ",
							"Temp cal 450         ",
							"Serial DEBUG        ",
							"Disp Temp. filter    ",
							"Start at prev. temp ",
							"3-button mode        ",
							"-Load Default-       ",
							"-Save and Reboot- ",
							"-Exit no Save-        "};

/* PID data */
float PID_setpoint = 0.0;

/* Flags for temp and current measurements */
uint8_t current_measurement_requested = 0;
uint8_t current_measurement_done = 1;
uint8_t thermocouple_measurement_requested = 0;
uint8_t thermocouple_measurement_done = 1;

/* Moving average filters for sensor data */
FilterTypeDef thermocouple_temperature_filter_struct;
FilterTypeDef thermocouple_temperature_filtered_filter_struct;
FilterTypeDef requested_power_filtered_filter_struct;
FilterTypeDef mcu_temperature_filter_struct;
FilterTypeDef input_voltage_filterStruct;
FilterTypeDef current_filterStruct;
FilterTypeDef stand_sense_filterStruct;
FilterTypeDef handle1_sense_filterStruct;
FilterTypeDef handle2_sense_filterStruct;

/* Hysteresis filters for sensor data */
Hysteresis_FilterTypeDef thermocouple_temperature_filtered_hysteresis;

/* USER CODE END PTD */

ADC_HandleTypeDef hadc1;
ADC_HandleTypeDef hadc2;
DMA_HandleTypeDef hdma_adc1;

CRC_HandleTypeDef hcrc;

I2C_HandleTypeDef hi2c1;

SPI_HandleTypeDef hspi2;
DMA_HandleTypeDef hdma_spi2_tx;

TIM_HandleTypeDef htim1;
TIM_HandleTypeDef htim2;
TIM_HandleTypeDef htim4;
TIM_HandleTypeDef htim6;
TIM_HandleTypeDef htim7;
TIM_HandleTypeDef htim8;
TIM_HandleTypeDef htim16;
TIM_HandleTypeDef htim17;

UART_HandleTypeDef huart1;
DMA_HandleTypeDef hdma_usart1_tx;

void SystemClock_Config(void);
static void MX_GPIO_Init(void);
static void MX_DMA_Init(void);
static void MX_ADC1_Init(void);
static void MX_ADC2_Init(void);
static void MX_CRC_Init(void);
static void MX_TIM1_Init(void);
static void MX_TIM2_Init(void);
static void MX_TIM4_Init(void);
static void MX_SPI2_Init(void);
static void MX_I2C1_Init(void);
static void MX_TIM17_Init(void);
static void MX_USART1_UART_Init(void);
static void MX_TIM7_Init(void);
static void MX_TIM8_Init(void);
static void MX_TIM6_Init(void);
static void MX_TIM16_Init(void);
/* USER CODE BEGIN 0 */
PID_TypeDef TPID;

/* Function to clamp d between the limits min and max */
float clamp(float d, float min, float max) {
  const float t = d < min ? min : d;
  return t > max ? max : t;
}

/* Function to get min value of a and b */
float min(float a, float b) {
  return a < b ? a : b;
}

/* Returns the average of 100 readings of the index+3*n value in the ADC_buffer vector */
float get_mean_ADC_reading_indexed(uint8_t index){
	float ADC_filter_mean = 0;
	for(int n=index;n<ADC1_BUF_LEN;n=n+3){
		ADC_filter_mean += ADC1_BUF[n];
	}
	return ADC_filter_mean/(ADC1_BUF_LEN/3.0);
}

/* Function to get the hardware version based on version bit pins */
uint8_t get_hw_version(){
	return 3 + (HAL_GPIO_ReadPin(GPIOC, VERSION_BIT_3_Pin) << 2) + (HAL_GPIO_ReadPin(GPIOC, VERSION_BIT_2_Pin) << 1) + (HAL_GPIO_ReadPin(GPIOC, VERSION_BIT_1_Pin)); //version counting starts at version 3
}

/* Convert RGB colour to BRG color */
uint16_t RGB_to_BRG(uint16_t color){
	return ((((color & 0b0000000000011111)  << 11) & 0b1111100000000000) | ((color & 0b1111111111100000) >> 5));
}

/* Function to change the main state */
void change_state(mainstates new_state){
	sensor_values.previous_state = sensor_values.current_state;
	sensor_values.current_state = new_state;
	// If transitioning to RUN and temperature should be saved for use as start-up temp
	if((sensor_values.previous_state != RUN) && (sensor_values.current_state == RUN) && (flash_values.startup_temp_is_previous_temp == 1)){
		flash_values.startup_temperature = sensor_values.set_temperature;
		FlashWrite(&flash_values);
	}
	if((sensor_values.current_state == RUN) && (flash_values.GPIO4_ON_at_run == 1)){
		HAL_GPIO_WritePin(GPIOB, USR_4_Pin, GPIO_PIN_SET);
	}
	else{
		HAL_GPIO_WritePin(GPIOB, USR_4_Pin, GPIO_PIN_RESET);
	}
}

/* Function to get the filtered MCU temperature */
void get_mcu_temp(){
	sensor_values.mcu_temperature =	Moving_Average_Compute((((get_mean_ADC_reading_indexed(2) * VSENSE) - V30) / Avg_Slope + 25), &mcu_temperature_filter_struct); //Index 2 is MCU temp
}

/* Function to get the filtered bus voltage */
void get_bus_voltage(){
	sensor_values.bus_voltage = Moving_Average_Compute(get_mean_ADC_reading_indexed(0), &input_voltage_filterStruct)*VOLTAGE_COMPENSATION; //Index 0 is bus voltage
}

/* Function to get the filtered heater current */
void get_heater_current(){
	sensor_values.heater_current = Moving_Average_Compute(current_raw, &current_filterStruct)*CURRENT_COMPENSATION;
}
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
int main(void)
{
  /* MCU Configuration--------------------------------------------------------*/

  /* Reset of all peripherals, Initializes the Flash interface and the Systick. */
  HAL_Init();

  /* Configure the system clock */
  SystemClock_Config();

  /* Initialize all configured peripherals */
  MX_GPIO_Init();
  MX_DMA_Init();
  MX_ADC1_Init();
  MX_ADC2_Init();
  MX_CRC_Init();
  MX_TIM1_Init();
  MX_TIM2_Init();
  MX_TIM4_Init();
  MX_SPI2_Init();
  MX_I2C1_Init();
  MX_TIM17_Init();
  MX_USART1_UART_Init();
  MX_TIM7_Init();
  MX_TIM8_Init();
  MX_TIM6_Init();
  MX_TIM16_Init();
  /* USER CODE BEGIN 2 */

	set_heater_duty(0);		//Set heater duty to zero to ensure zero startup current
	HAL_TIMEx_PWMN_Start_IT(&htim1, TIM_CHANNEL_3);

	HAL_TIM_Encoder_Start_IT(&htim2, TIM_CHANNEL_ALL);
	HAL_TIM_PWM_Start_IT(&htim1, TIM_CHANNEL_1);
	__HAL_TIM_SET_COMPARE(&htim4, TIM_CHANNEL_2, 5); //Set BUZZER duty to 50%
	HAL_TIM_Base_Start_IT(&htim6);

	__HAL_TIM_ENABLE_IT(&htim7, TIM_IT_UPDATE);

	HAL_ADCEx_Calibration_Start(&hadc2, ADC_SINGLE_ENDED);

	HAL_ADCEx_Calibration_Start(&hadc1, ADC_SINGLE_ENDED);
	HAL_ADC_Start_DMA(&hadc1, (uint32_t*)ADC1_BUF, (uint32_t)ADC1_BUF_LEN);	//Start ADC DMA mode

  /* USER CODE END 2 */

  /* Infinite loop */
  /* USER CODE BEGIN WHILE */
	HAL_Delay(200);

	// Check if user data in flash is valid, if not - write default parameters
	if(!FlashCheckCRC()){
		FlashWrite(&default_flash_values);
		beep(1); //Beep once to indicate default parameters written to flash
		HAL_Delay(100);
	}

	/* Read flash data */
	FlashRead(&flash_values);

	/* Initiate display */
	LCD_init();
	LCD_SetRotation(flash_values.screen_rotation);

	/* Set startup state */
	change_state(HALTED);

	/* start settings menu */
	settings_menu();

	/* Set initial encoder timer value */
	TIM2->CNT = flash_values.startup_temperature;

	/* initialize moving average functions */
	Moving_Average_Init(&thermocouple_temperature_filter_struct,(uint32_t)2);
	Moving_Average_Init(&thermocouple_temperature_filtered_filter_struct,(uint32_t)flash_values.displayed_temp_filter*10);
	Moving_Average_Init(&requested_power_filtered_filter_struct,(uint32_t)20);
	Moving_Average_Init(&mcu_temperature_filter_struct,(uint32_t)100);
	Moving_Average_Init(&input_voltage_filterStruct,(uint32_t)25);
	Moving_Average_Init(&current_filterStruct,(uint32_t)5);
	Moving_Average_Init(&stand_sense_filterStruct,(uint32_t)20);
	Moving_Average_Init(&handle1_sense_filterStruct,(uint32_t)20);
	Moving_Average_Init(&handle2_sense_filterStruct,(uint32_t)20);

	/* initialize hysteresis functions */
	Hysteresis_Init(&thermocouple_temperature_filtered_hysteresis, 0.5);

	/* Initiate PID controller */
	PID(&TPID, &sensor_values.thermocouple_temperature, &sensor_values.requested_power, &PID_setpoint, 0, 0, 0, _PID_CD_DIRECT); //PID parameters are set depending on detected handle by set_handle_values()
	PID_SetMode(&TPID, _PID_MODE_AUTOMATIC);
	PID_SetSampleTime(&TPID, PID_UPDATE_INTERVAL, 0); 		// Set PID update time to "PID_UPDATE_INTERVAL"
	PID_SetOutputLimits(&TPID, 0, PID_MAX_OUTPUT); 			// Set max and min output limit
	PID_SetILimits(&TPID, 0, 0);         					// Set max and min I limit
	PID_SetIminError(&TPID,PID_ADD_I_MIN_ERROR);
	PID_SetNegativeErrorIgainMult(&TPID, PID_NEG_ERROR_I_MULT, PID_NEG_ERROR_I_BIAS); // Set un-symmetric I gain parameters

	/* Init and fill filter structures with initial values */
	for (int i = 0; i<200;i++){
		get_bus_voltage();
		get_heater_current();
		get_mcu_temp();
		get_thermocouple_temperature();
		get_handle_type();
		set_handle_values();
		get_stand_status();
		handle_button_status();
		handle_cartridge_presence();
	}

	/* check STUSB4500 */
	HAL_StatusTypeDef halStatus;
	halStatus  = stusb_check_connection();
	if(halStatus != HAL_OK){
		//do error handling for STUSB
		debug_print_str(DEBUG_ERROR,"STUSB4500 unavailable");
	}else{
		debug_print_str(DEBUG_INFO,"STUSB4500 found");

		stusb_init();

		//1. check if cable is connected
		if(stusb_is_sink_connected()){

			//2. wait for sink to get ready
			while(!stusb_is_sink_ready()){
				debug_print_str(DEBUG_INFO,"Waiting for sink to get ready");
			}
			//if we are on USB-PD the sink needs some time to start
			HAL_Delay(500);

			stusb_soft_reset();

			//check if USB-PD is available
			STUSB_GEN1S_RDO_REG_STATUS_RegTypeDef rdo;
			halStatus = stusb_read_rdo(&rdo);
			volatile uint8_t currendPdoIndex = rdo.b.Object_Pos;
			if(currendPdoIndex == 0){
				debug_print_str(DEBUG_INFO,"No USB-PD detected");
			}else{
				power_source = POWER_USB;
				//The usb devices need some time to transmit the messages and execute the soft reset
				//HAL_Delay(4);
				//poll alert status since we don't have the alert interrupt pin connected
				//depending on the source we may need a few tries
				bool sourceStatus = false;
				for(int i=0;i<500;i++){
					sourceStatus = poll_source();
					if(sourceStatus){
						debug_print_str(DEBUG_INFO,"Got PDOs");
						uint8_t maxPowerAvailable = 0;
						stusb_set_highest_pdo(&maxPowerAvailable, currendPdoIndex);

						sensor_values.USB_PD_power_limit = maxPowerAvailable*USB_PD_POWER_REDUCTION_FACTOR;
						debug_print_int(DEBUG_INFO,"Reduced max power to", maxPowerAvailable*USB_PD_POWER_REDUCTION_FACTOR);
						//re-negotiate
						break;
					}
				}
			}
		}else{
			debug_print_str(DEBUG_INFO,"No USB-PD sink connected");
		}
	}

	/* Draw the main screen decoration */
	LCD_draw_main_screen();

	/* Start-up beep */
	beep_startup(flash_values.startup_beep);

	//Flag to indicate that the startup sequence is done
	startup_done = 1;
	sensor_values.thermocouple_temperature_previous = sensor_values.thermocouple_temperature;

	while (1){
		if(HAL_GetTick() - previous_sensor_update_high_update >= interval_sensor_update_high_update){
			get_stand_status();
			get_handle_type();
			set_handle_values();
			get_set_temperature();
			handle_button_status();
			handle_emergency_shutdown();
			handle_cartridge_presence();
			//handle_delta_temperature();
			previous_sensor_update_high_update = HAL_GetTick();
		}

		if(HAL_GetTick() - previous_sensor_update_low_update >= interval_sensor_update_low_update){
			get_bus_voltage();
			get_heater_current();
			get_mcu_temp();
			previous_sensor_update_low_update = HAL_GetTick();
		}

		/* Compute PID */
		PID_Compute(&TPID);

		/* switch */
		switch(sensor_values.current_state) {
			case RUN: {
				PID_setpoint = sensor_values.set_temperature;
				break;
			}
			case STANDBY: {
			  if(flash_values.standby_temp > sensor_values.set_temperature){
				PID_setpoint = sensor_values.set_temperature;
			  }
			  else{
				PID_setpoint = flash_values.standby_temp;
			  }
			  break;
			}
			case SLEEP:
			case EMERGENCY_SLEEP:
			case HALTED: {
				PID_setpoint = 0;
				break;
			}
		}

		/* PID Tuning manual control */
		#ifdef PID_TUNING
		custom_temperature_on = 1;
		PID_SetTunings(&TPID, Kp_tuning, Ki_tuning, Kd_tuning/100.0);
		PID_SetILimits(&TPID, -PID_MAX_I_LIMIT_tuning, PID_MAX_I_LIMIT_tuning); 	// Set max and min I limit
		sensor_values.set_temperature = temperature_tuning;
		#endif

		/* Send debug information */
		if(flash_values.serial_debug_print == 1){
			if(HAL_GetTick() - previous_millis_debug >= interval_debug){
				UART_packet_length = 9*sizeof(float);
				pack_frame_start(UART_transmit_buffer, &UART_packet_index, UART_packet_length);
				pack_float(UART_transmit_buffer, &UART_packet_index, (float)sensor_values.thermocouple_temperature);
				pack_float(UART_transmit_buffer, &UART_packet_index, (float)sensor_values.thermocouple_temperature_filtered);
				pack_float(UART_transmit_buffer, &UART_packet_index, (float)PID_setpoint);
				pack_float(UART_transmit_buffer, &UART_packet_index, (float)sensor_values.requested_power/PID_MAX_OUTPUT*100.0);
				pack_float(UART_transmit_buffer, &UART_packet_index, (float)sensor_values.requested_power_filtered/PID_MAX_OUTPUT*100.0);
				pack_float(UART_transmit_buffer, &UART_packet_index, (float)PID_GetPpart(&TPID)/10.0);
				pack_float(UART_transmit_buffer, &UART_packet_index, (float)PID_GetIpart(&TPID)/10.0);
				pack_float(UART_transmit_buffer, &UART_packet_index, (float)PID_GetDpart(&TPID)/10.0);
				pack_float(UART_transmit_buffer, &UART_packet_index, (float)sensor_values.heater_current);

				HAL_UART_Transmit_DMA(&huart1,(uint8_t*)UART_transmit_buffer, UART_packet_length+2); // Add two for starting bit and packet length
				previous_millis_debug = HAL_GetTick();
			}
		}
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

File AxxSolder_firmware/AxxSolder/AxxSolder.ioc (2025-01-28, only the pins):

Mcu.UserName=STM32G431CBTx
PA0.GPIO_Label=ENC_A
PA0.Signal=S_TIM2_CH1
PA1.GPIO_Label=I_LEAK
PA1.Signal=ADC2_IN2
PA10.Signal=USART1_RX
PA13.Signal=SYS_JTMS-SWDIO
PA14.Signal=SYS_JTCK-SWCLK
PA15.Signal=I2C1_SCL
PA2.GPIO_Label=VBUS
PA2.Signal=ADC1_IN3
PA3.GPIO_Label=THERMOCOUPLE
PA3.Signal=ADC1_IN4
PA4.GPIO_Label=HANDLE_INP_1
PA4.Signal=GPIO_Input
PA5.GPIO_Label=HANDLE_INP_2
PA5.Signal=GPIO_Input
PA6.GPIO_Label=STAND_INP
PA6.Signal=GPIO_Input
PA7.GPIO_Label=SW_2
PA7.Signal=GPXTI7
PA8.GPIO_Label=USR_1
PA8.Signal=GPIO_Output
PA9.Signal=USART1_TX
PB0.GPIO_Label=USR_2
PB0.Signal=GPIO_Output
PB1.GPIO_Label=USR_3
PB1.Signal=GPIO_Output
PB10.GPIO_Label=SPI2_SD_CS
PB10.Signal=GPIO_Output
PB11.GPIO_Label=SPI2_DC
PB11.Signal=GPIO_Output
PB12.GPIO_Label=SPI2_RST
PB12.Signal=GPIO_Output
PB13.Signal=SPI2_SCK
PB14.GPIO_Label=SPI2_CS
PB14.Signal=GPIO_Output
PB15.Signal=SPI2_MOSI
PB2.GPIO_Label=USR_4
PB2.Signal=GPIO_Output
PB3.GPIO_Label=ENC_B
PB3.Signal=S_TIM2_CH2
PB5.GPIO_Label=SW_1
PB5.Signal=GPXTI5
PB7.GPIO_Label=BUZZER
PB7.Signal=S_TIM4_CH2
PB8-BOOT0.GPIO_Label=SW_3
PB8-BOOT0.Signal=GPXTI8
PB9.Signal=I2C1_SDA
PC13.GPIO_Label=VERSION_BIT_1
PC13.Signal=GPIO_Input
PC14-OSC32_IN.GPIO_Label=VERSION_BIT_2
PC14-OSC32_IN.Signal=GPIO_Input
PC15-OSC32_OUT.GPIO_Label=VERSION_BIT_3
PC15-OSC32_OUT.Signal=GPIO_Input
PF0-OSC_IN.GPIO_Label=HEATER
PF0-OSC_IN.Signal=TIM1_CH3N
PF1-OSC_OUT.GPIO_Label=CURRENT
PF1-OSC_OUT.Signal=ADC2_IN10

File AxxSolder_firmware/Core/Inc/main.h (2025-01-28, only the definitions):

#define VERSION_BIT_1_Pin GPIO_PIN_13
#define VERSION_BIT_1_GPIO_Port GPIOC
#define VERSION_BIT_2_Pin GPIO_PIN_14
#define VERSION_BIT_2_GPIO_Port GPIOC
#define VERSION_BIT_3_Pin GPIO_PIN_15
#define VERSION_BIT_3_GPIO_Port GPIOC
#define HEATER_Pin GPIO_PIN_0
#define HEATER_GPIO_Port GPIOF
#define CURRENT_Pin GPIO_PIN_1
#define CURRENT_GPIO_Port GPIOF
#define ENC_A_Pin GPIO_PIN_0
#define ENC_A_GPIO_Port GPIOA
#define I_LEAK_Pin GPIO_PIN_1
#define I_LEAK_GPIO_Port GPIOA
#define VBUS_Pin GPIO_PIN_2
#define VBUS_GPIO_Port GPIOA
#define THERMOCOUPLE_Pin GPIO_PIN_3
#define THERMOCOUPLE_GPIO_Port GPIOA
#define HANDLE_INP_1_Pin GPIO_PIN_4
#define HANDLE_INP_1_GPIO_Port GPIOA
#define HANDLE_INP_2_Pin GPIO_PIN_5
#define HANDLE_INP_2_GPIO_Port GPIOA
#define STAND_INP_Pin GPIO_PIN_6
#define STAND_INP_GPIO_Port GPIOA
#define SW_2_Pin GPIO_PIN_7
#define SW_2_GPIO_Port GPIOA
#define SW_2_EXTI_IRQn EXTI9_5_IRQn
#define USR_2_Pin GPIO_PIN_0
#define USR_2_GPIO_Port GPIOB
#define USR_3_Pin GPIO_PIN_1
#define USR_3_GPIO_Port GPIOB
#define USR_4_Pin GPIO_PIN_2
#define USR_4_GPIO_Port GPIOB
#define SPI2_SD_CS_Pin GPIO_PIN_10
#define SPI2_SD_CS_GPIO_Port GPIOB
#define SPI2_DC_Pin GPIO_PIN_11
#define SPI2_DC_GPIO_Port GPIOB
#define SPI2_RST_Pin GPIO_PIN_12
#define SPI2_RST_GPIO_Port GPIOB
#define SPI2_CS_Pin GPIO_PIN_14
#define SPI2_CS_GPIO_Port GPIOB
#define USR_1_Pin GPIO_PIN_8
#define USR_1_GPIO_Port GPIOA
#define ENC_B_Pin GPIO_PIN_3
#define ENC_B_GPIO_Port GPIOB
#define SW_1_Pin GPIO_PIN_5
#define SW_1_GPIO_Port GPIOB
#define SW_1_EXTI_IRQn EXTI9_5_IRQn
#define BUZZER_Pin GPIO_PIN_7
#define BUZZER_GPIO_Port GPIOB
#define SW_3_Pin GPIO_PIN_8
#define SW_3_GPIO_Port GPIOB
#define SW_3_EXTI_IRQn EXTI9_5_IRQn

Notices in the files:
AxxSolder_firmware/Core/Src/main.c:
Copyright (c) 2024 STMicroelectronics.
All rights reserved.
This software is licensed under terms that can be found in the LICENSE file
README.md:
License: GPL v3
